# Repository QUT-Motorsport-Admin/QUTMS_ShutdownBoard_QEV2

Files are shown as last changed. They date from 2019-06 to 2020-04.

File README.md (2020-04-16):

QUTMS_Banner
# Shutdown Board V2
Saftey System shutdown board dedicated to managing the vehicle shutdown loop.

## Function
Disables the car by opening the shutdown loop if at least one shudown device reports a fault. It also reports which devices are open circuit in the shutdown loop using sense wires in the wiring harness.

## Subsystems
* Shutdown loop latching for HVD, IMD, BMS, PDOC, MCU and BSPD.
* Brake Sensor Plausibility Device (BSPD).
* Shutdown node sensing and reporting.

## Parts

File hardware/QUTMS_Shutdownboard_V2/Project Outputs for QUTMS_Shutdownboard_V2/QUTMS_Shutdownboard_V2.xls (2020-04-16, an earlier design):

Item # | Designator | Description | Name | Quantity | Manufacturer 1 | Manufacturer Part Number 1 | Footprint | LibRef | Note
1 | C1, C3, C4, C5, C15, C16 | CAP 100nF 16V ±5% 0603 (1608 Metric) Thickness 1mm SMD | CAP 100nF 16V 0603(1608) | 6 | KEMET | C0603C104J4RAC | CAPC0603(1608)100_M | CMP-1035-02583-1
2 | C2 | Chip Capacitor, 10 uF, +/- 10%, 16 V, -25 to 85 degC, 0805 (2012 Metric), RoHS, Tape and Reel | EMK212BJ106KG-T | 1 | Taiyo Yuden | EMK212BJ106KG-T | CAPC2013X135X50ML10T25 | CMP-2000-05449-1
3 | C6, C11 | CAP 100nF 16V ±10% 0603 (1608 Metric) Thickness 1mm SMD | CAP 100nF 16V 0603(1608) | 2 | Yageo | CC0603KRX7R7BB104 | CAPC0603(1608)100_N | CMP-1035-02584-1
4 | C12 | CAP 4.7nF 50V ±5% 0603 (1608 Metric) Thickness 1mm SMD | CAP 4.7nF 50V 0603(1608) | 1 | KEMET | C0603C472J5RACTU | CAPC0603(1608)100_M | CMP-1035-02202-1
5 | C13, C14 | CAP 22pF 16V ±5% 0603 (1608 Metric) Thickness 1mm SMD | CAP 22pF 16V 0603(1608) | 2 | KEMET | C0603C220J4GACTU | CAPC0603(1608)100_N | CMP-1035-00808-1
6 | C17, C18 | CAP 22pF 16V ±1% 0603 (1608 Metric) Thickness 1mm SMD | CAP 22pF 16V 0603(1608) | 2 | Vishay Vitramon | VJ0603A220FXJPW1BC | CAPC0603(1608)100_L | CMP-1035-00806-1
7 | C19 | CAP 100nF 25V ±5% 0603 (1608 Metric) Thickness 1mm SMD | CAP 100nF 25V 0603(1608) | 1 | Yageo | CC0603JRX7R8BB104 | CAPC0603(1608)100_N | CMP-1035-02587-1
8 | C20 | Chip Capacitor, 10 uF, +/- 10%, 25 V, -55 to 85 degC, 1210 (3225 Metric), RoHS, Tape and Reel | 12103D106KAT2A | 1 | Kyocera AVX | 12103D106KAT2A | CAPC3225X279X50LL20T25 | CMP-2000-05477-1
9 | C21 | CAP 10uF 16V ±10% 0805 (2012 Metric) Thickness 1mm SMD | CAP 10uF 16V 0805(2012) | 1 |  |  | CAPC0805(2012)100_L | CMP-1036-04928-1
10 | DS1 | Chip LED, Green, 574 nm, 40 pF, -55 to 85 degC, 2-Pin SMD, RoHS, Tape and Reel | LTST-C191KGKT | 1 | Vishay Lite-On | LTST-C191KGKT | LITE-ON-LTST-C191KRKT-2_V | CMP-2000-05198-1
11 | J1 | Conn Wire to Board RCP 34 POS 1.5mm Solder RA Thru-Hole Automotive Tube | 6437288-2 | 1 |  |  | TE_6437288-2 | 6437288-2
12 | K1, K2, K3, K4, K5, K6 | DPDT 2 Form C (CO) Low Power PCB Relay, 24 VDC, 8 A, -40 to 85 degC, 8-Pin THD, RoHS, Tube | RT424024 | 6 | TE Connectivity | RT424024 | TECO-RT424024_V | CMP-2000-06999-1
13 | L2 | Fixed Inductor, 10 uH, +/-20%, -55 to 125 degC, 2-Pin SMD (0805), RoHS, Tape and Reel | LQM21FN100M70L | 1 | Murata | LQM21FN100M70L | MURA-IND0805_L | CMP-2000-06587-1
14 | LED1, LED2, LED3, LED4 | LED, SMT, 0603(1608), 0.25mm Tthickness, Super Bright Orange | APG1608SEKC/T | 4 | Kingbright | APG1608SEKC/T | KING-LED0603-25-ORANGE_V | CMP-0239-00002-1
15 | P1, P2 | Header, 3-Pin, Right Angle | Header 3H | 2 |  |  | HDR1X3H | Header 3H
16 | P3 | UART Header | UART Header | 1 |  |  | HDR1X2 | Header 2
17 | P4 | Header, 3-Pin, Dual row | Header 3X2 | 1 |  |  | HDR2X3 | Header 3X2
18 | P5, P6, P7, P8, P9, P10 | Header, 2-Pin | Header 2 | 6 |  |  | HDR1X2 | Header 2
19 | Q1, Q3, Q5, Q7, Q9 | Power MOSFET, -20 V, -1 A, P-Channel, 3-Pin SOT-23, Pb-Free, Tape and Reel | NTR1P02T1G | 5 | ON Semiconductor | NTR1P02T1G | ONSC-SOT-23-3-318-08_V | CMP-1058-00751-1
20 | Q2, Q4, Q6, Q8, Q10, Q11, Q12 | Power MOSFET, 750 mA, 20 V, N-Channel, 3-Pin SOT-23, Pb-Free, Tape and Reel | MGSF1N02LT1G | 7 | ON Semiconductor | MGSF1N02LT1-G | ONSC-SOT-23-3-318-08_V | CMP-1058-00777-1
21 | R1, R3, R5, R29, R31, R33, R34, R36, R38, R39, R41, R43, R44, R45, R47, R49, R54 | 10K 0.1W 5% 0603 (1608 Metric) SMD | 10K 5% 0603(1608) | 17 | Yageo | RC0603JR-0710KL | RESC0603(1608)_N | CMP-1012-00098-1
22 | R2, R7, R9, R12, R15, R18, R27, R30, R35, R40, R46, R52 | 4K7 0.1W 5% 0603 (1608 Metric) SMD | 4K7 5% 0603(1608) | 12 | Vishay Dale | CRCW06034K70JNEB | RESC0603(1608)_N | CMP-1012-00090-1
23 | R4, R32, R37, R42, R48, R53 | 220R 0.1W 5% 0603 (1608 Metric) SMD | 220R 5% 0603(1608) | 6 | Bourns | CR0603-JW-221ELF | RESC0603(1608)_M | CMP-1012-00058-1
24 | R6, R8, R10, R11, R13, R14, R17, R19, R20, R21 | Resistor | Res1 | 10 |  |  | AXIAL-0.3 | Res1
25 | R16 | 51K 0.1W 5% 0603 (1608 Metric) SMD | 51K 5% 0603(1608) | 1 | Vishay Dale | CRCW060351K0JNEA | RESC0603(1608)_M | CMP-1012-00115-1
26 | R22 | 300R 0.1W 5% 0603 (1608 Metric) SMD | 300R 5% 0603(1608) | 1 | Vishay Dale | CRCW0603300RJNEA | RESC0603(1608)_N | CMP-1012-00061-1
27 | R23, R24 | 60R4 0.5W 1% 1210 (3225 Metric) SMD | 60R4 1% 1210(3225) | 2 | Yageo | RC1210FR-0760R4L | RESC1210(3225)_L | CMP-1015-00372-1
28 | R25, R26, R50, R55, R56 | 330R 0.1W 5% 0603 (1608 Metric) SMD | 330R 5% 0603(1608) | 5 | Bourns | CR0603-JW-331ELF | RESC0603(1608)_L | CMP-1012-00062-1
29 | R28 | 3K 0.1W 5% 0603 (1608 Metric) SMD | 3K 5% 0603(1608) | 1 | Vishay Dale | CRCW06033K00JNEA | RESC0603(1608)_M | CMP-1012-00085-1
30 | R51 | 1K 0.1W 5% 0603 (1608 Metric) SMD | 1K 5% 0603(1608) | 1 | Vishay Dale | CRCW06031K00JNEB | RESC0603(1608)_L | CMP-1012-00074-1
31 | SW1 | Tactile Switch, 50 mA, 12 VDC, -20 to 85 degC, 4-Pin SMD, RoHS, Bulk | 4-1437565-1 | 1 | TE Connectivity | 4-1437565-1 | TECO-4-1437565-1_V | CMP-2000-05602-1
32 | SW2 | Ultra-Small Tactile Switch, 0.05 A, 12 V, -25 to 70 degC, 2-Pin SMD, RoHS, Tape and Reel | B3U-1000P | 1 | Omron | B3U-1000P | OMRON-B3U-1000_V | CMP-2100-03586-1
33 | U1 | Quad Differential Comparator, 2 to 30 V, 0 to 70 degC, 14-pin SOIC (D14), Green (RoHS & no Sb/Br), Tube | LM339D | 1 | Texas Instruments | LM339D | D0014A_L | CMP-2000-06548-1
34 | U2, U8, U9 | Single 2-Input Positive-NOR Gate, DBV0005A, LARGE T&R | SN74AHC1G02DBVR | 3 | Texas Instruments | SN74AHC1G02DBVR | DBV0005A_L | CMP-0859-00024-3
35 | U3 |  | MCP2517FD | 1 |  |  | MCP2517FD SOIC | MCP2517FD
36 | U4 |  | MCP2561 | 1 |  |  | MCP2561 SOIC | MCP2561
37 | U5 | Analog Multiplexer / Demultiplexer, 3 to 18 V, -55 to 125 degC, 24-Pin SOIC, Pb-Free, Tape and Reel | MC14067BDWR2G | 1 | ON Semiconductor | MC14067BDWR2G | ONSC-SOIC-24-751E-04_V | CMP-1307-00132-1
38 | U6 | 8-bit AVR Microcontroller, 128KB Flash, 4KB EEPROM, 16KB SRAM, 44-pin TQFP, Industrial Grade (-40°C to 85°C) | ATmega1284P-AU | 1 | Microchip / Atmel | ATMEGA1284P-AU | 44A_N | CMP-0095-00577-1
39 | U7 | Fixed Low Drop Positive Voltage Regulator, 5V, 4-Pin SOT-223, Tape and Reel | LD1117S50CTR | 1 | STMicroelectronics | LD1117S50CTR | SOT-223_N | CMP-0244-00311-1
40 | U10, U11, U12, U13, U14, U15 | 1 Form A Solid State Relay, 2 A, -40 to 85 degC, 6-Pin SMD, RoHS, Tape and Reel | VO14642AABTR | 6 | Vishay | VO14642AABTR | VISH-VO14642AABTR_V | CMP-2000-07398-1
41 | X1 |  | Crystal 20MHz | 1 |  |  | Crystal 20MHz | Crystal 20MHz
42 | X2 | ATS-SM Series Quartz Crystal, 16 MHz, -20 to 70 degC, 11.1 x 4.83 x 4.3mm SMD, RoHS, Tape and Reel | ATS16ASM-1 | 1 | CTS | ATS16ASM-1 | CTS-ATS-SM-XTAL-2 | CMP-0585-00002-2

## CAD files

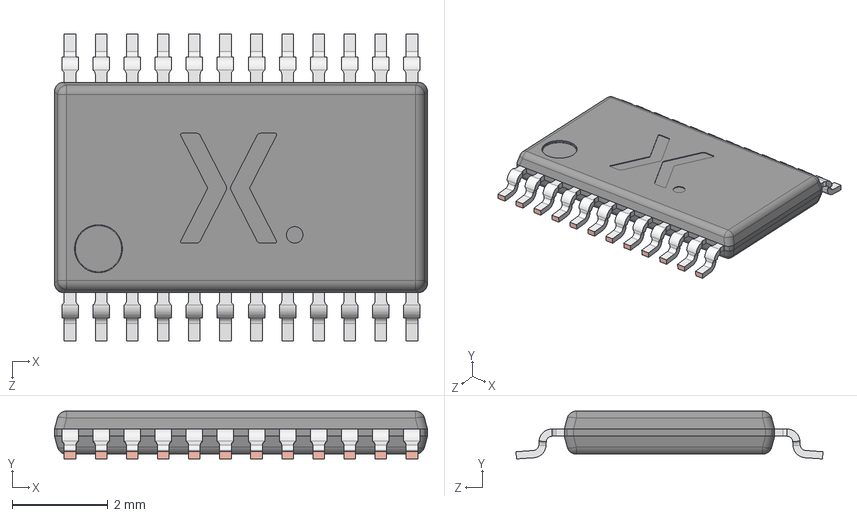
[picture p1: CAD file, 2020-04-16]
hardware/QUTMS_Shutdownboard_V2_1/SOT355-1.step
7.80 x 1.00 x 6.42 mm
SOT355-1 Lower Mold body
SOT355-1 Lead
SOT355-1 Upper Mold body

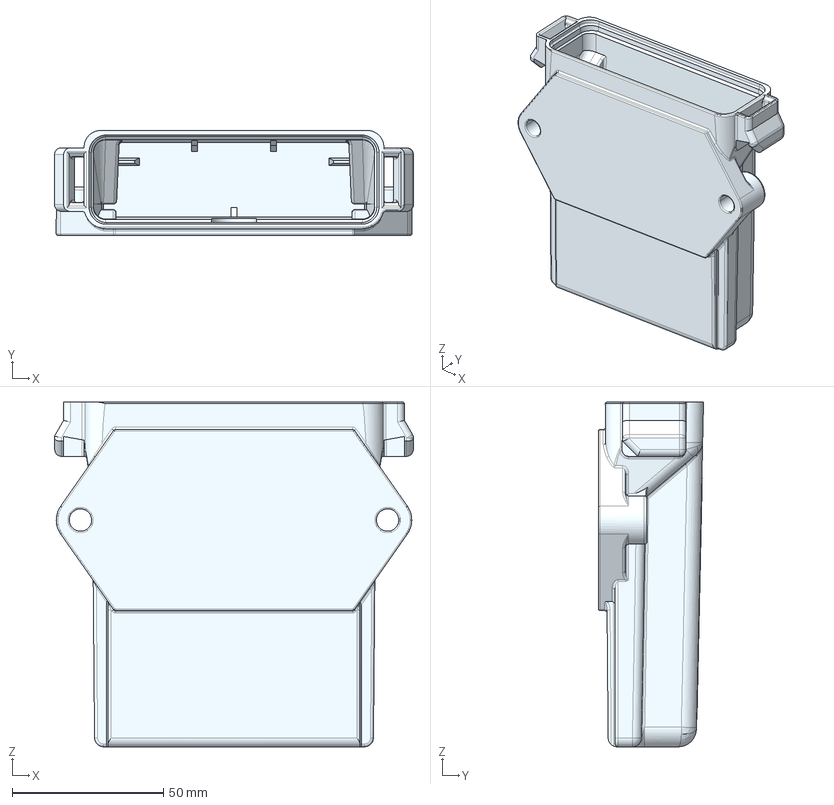
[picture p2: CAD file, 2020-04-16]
hardware/QUTMS_ShutdownBoard_V2_1_Assembly/c-eec-325x4b-e016-99-3d.stp
118.7 x 34.7 x 114.0 mm

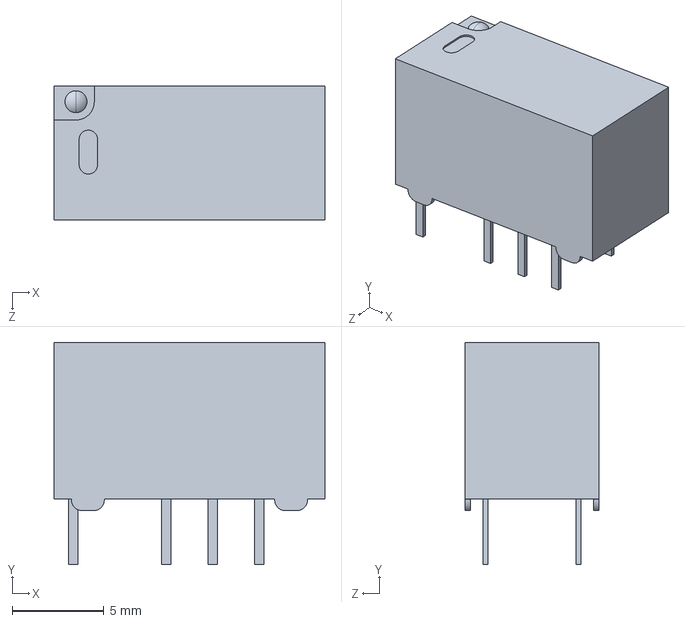
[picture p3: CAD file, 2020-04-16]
hardware/QUTMS_Shutdownboard_V2_1_BeforeSplit_FROZEN/G6S_2.step
14.8 x 12.2 x 7.30 mm

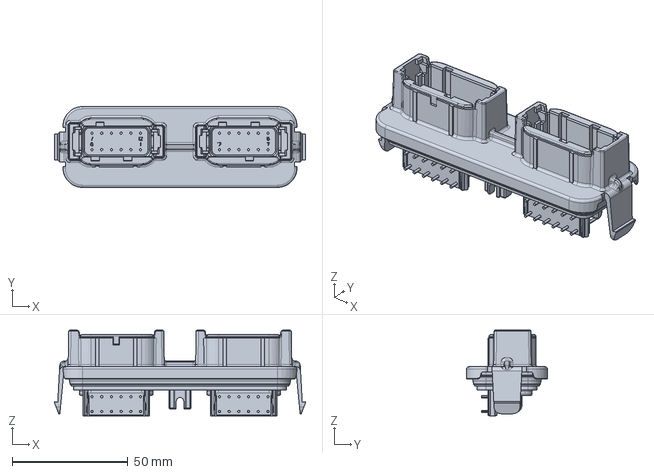
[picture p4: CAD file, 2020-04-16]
hardware/QUTMS_Shutdownboard_V2_1/c-dtm1312pa12pbgr01-c-3d.stp
108.3 x 35.0 x 36.9 mm

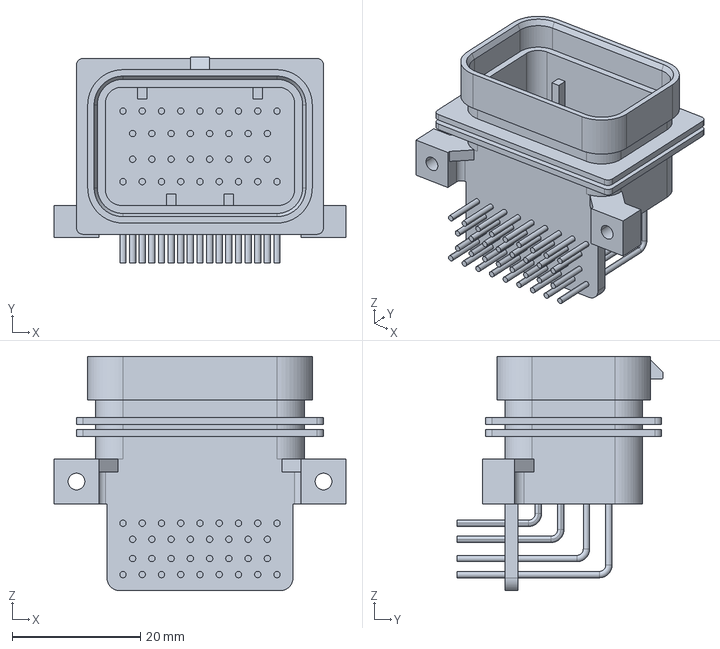
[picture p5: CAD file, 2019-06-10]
hardware/QUTMS_Shutdownboard_V2_1/c-6437288-2-c-3d.stp
45.5 x 32.1 x 36.5 mm

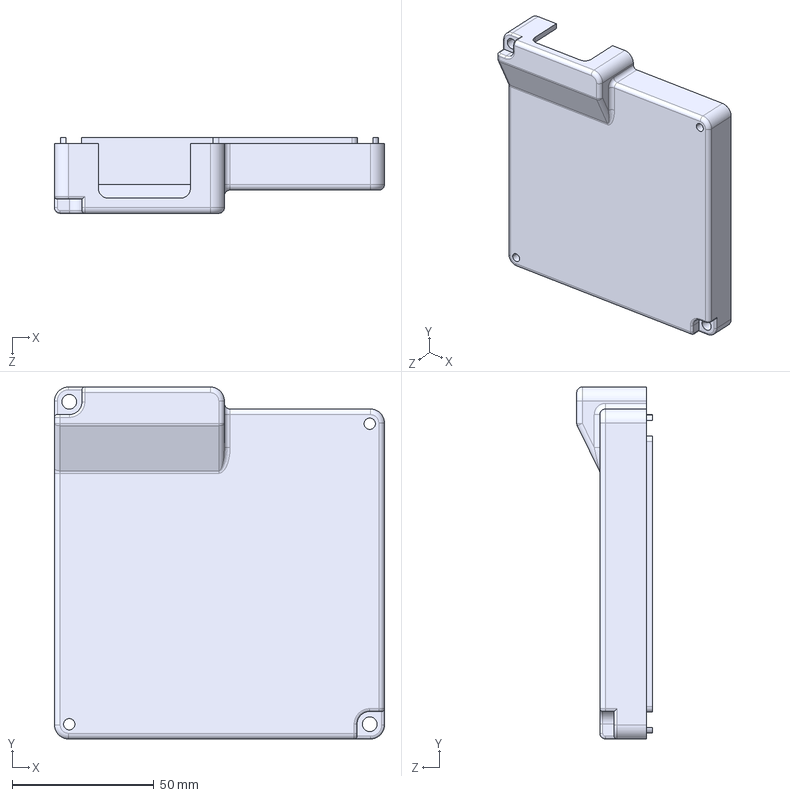
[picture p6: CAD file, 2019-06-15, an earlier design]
hardware/QUTMS_Shutdownboard_V2/SHUTDOWN BOARD CASE TOP.STEP
116.5 x 124.2 x 26.7 mm

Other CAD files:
hardware/QUTMS_Shutdownboard_V2/SHUTDOWN BOARD CASE BOTTOM.IGS
hardware/QUTMS_Shutdownboard_V2/SHUTDOWN BOARD CASE BOTTOM.STEP
hardware/QUTMS_Shutdownboard_V2/SHUTDOWN BOARD CASE TOP.IGS

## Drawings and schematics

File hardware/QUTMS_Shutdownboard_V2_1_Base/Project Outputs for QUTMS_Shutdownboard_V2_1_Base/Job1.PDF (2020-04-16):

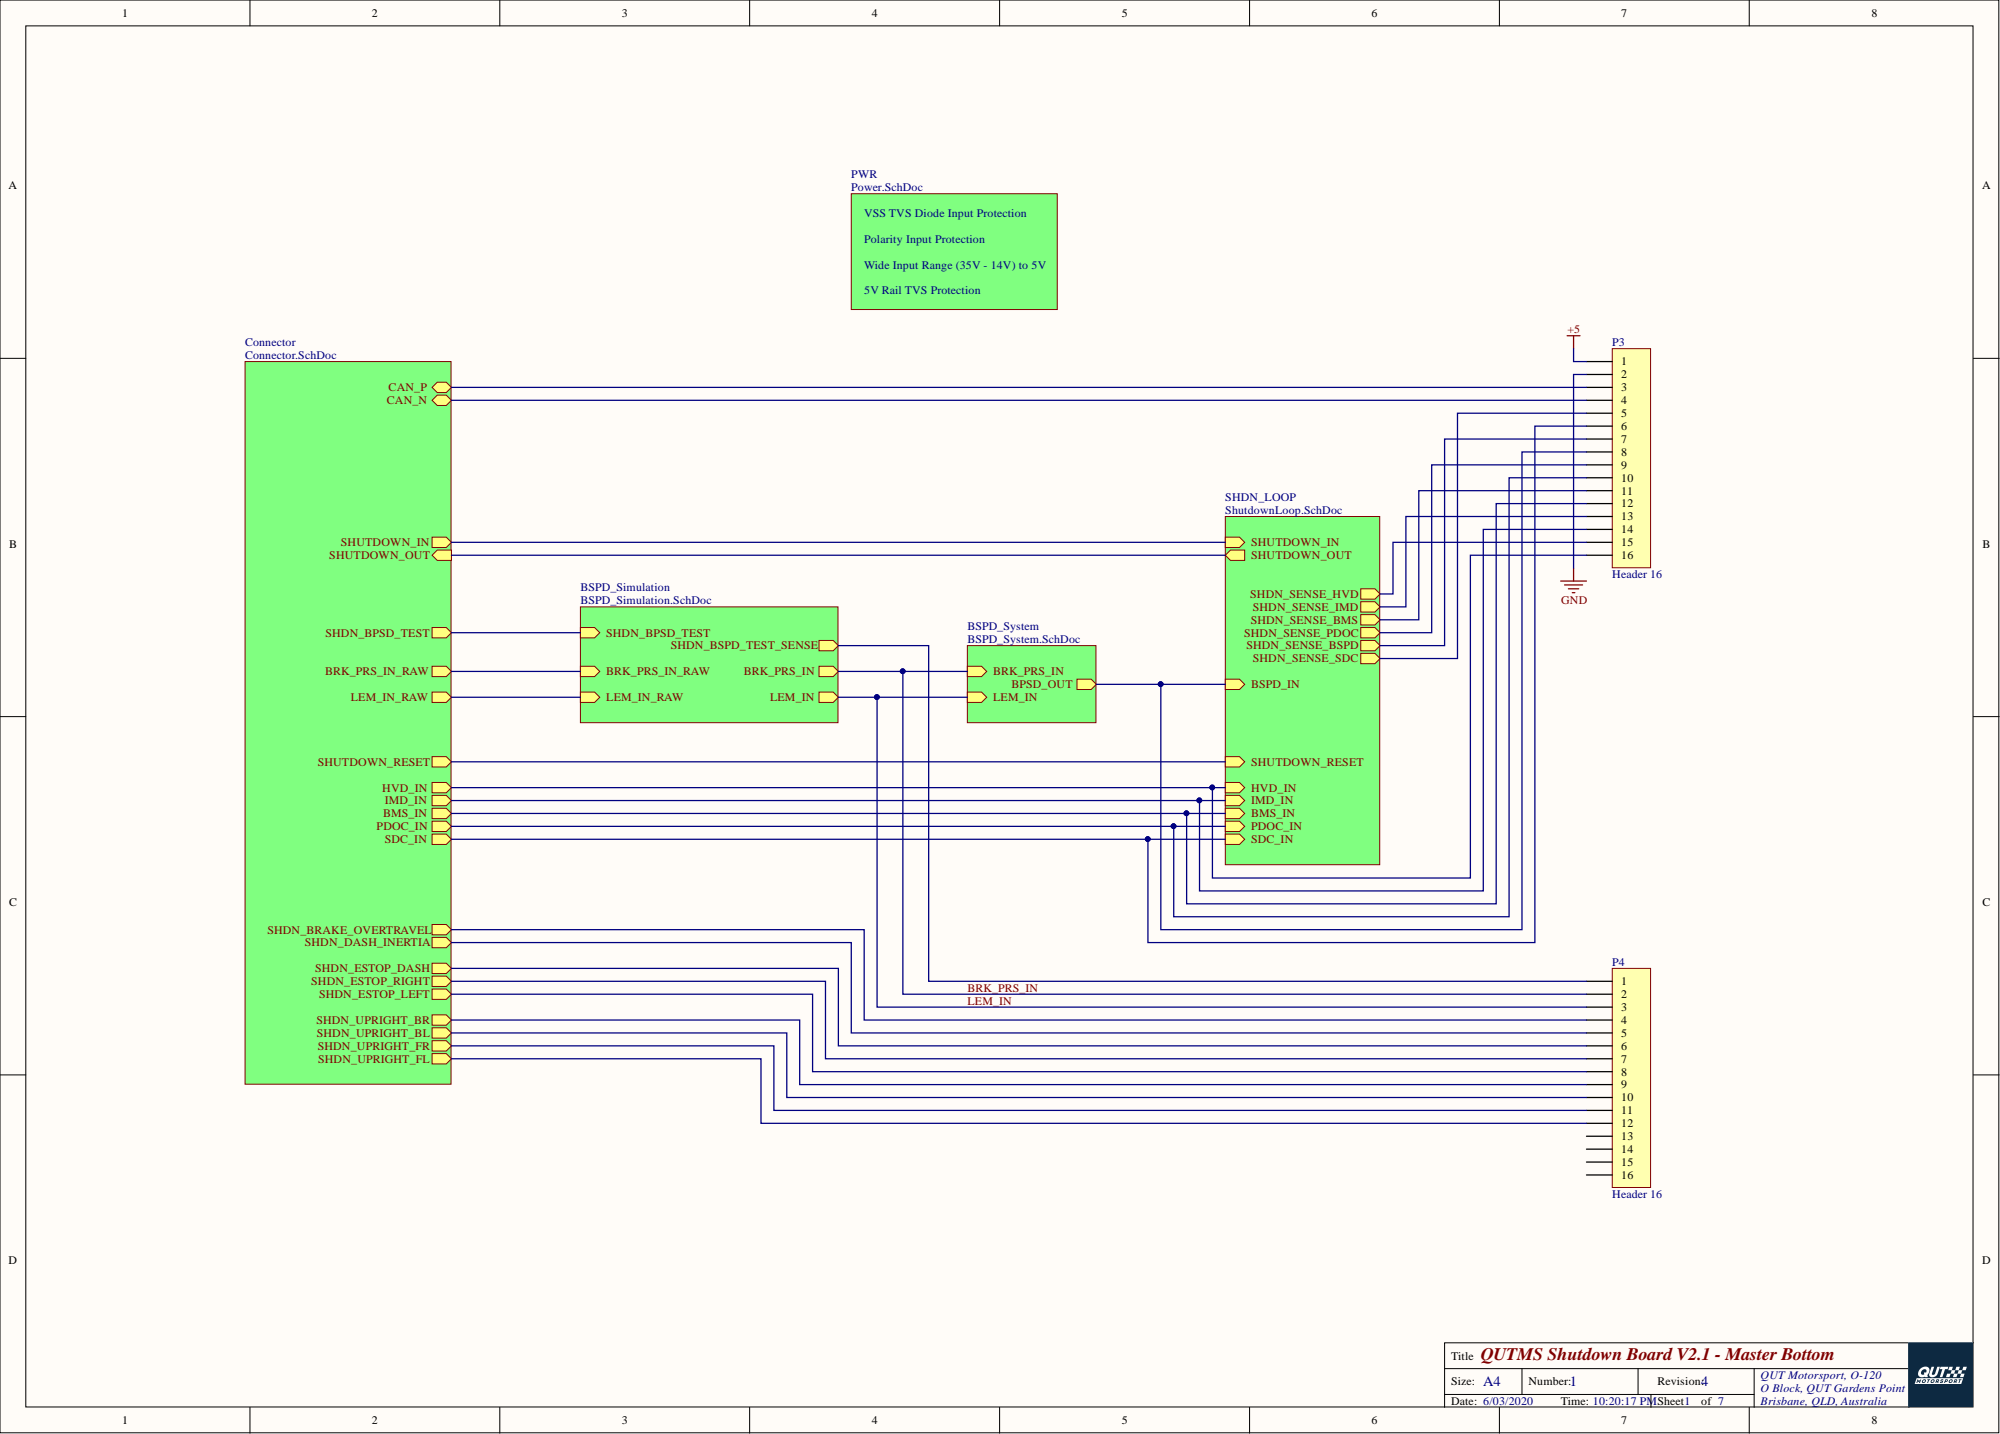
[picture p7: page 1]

SH D N _ L O O P
Sh u t d o w n L o o p.Sch D o c

BSPD _Simu lat i o n BSPD _Simu lat i o n.Sch D o c | | SH U T D O W N _ O U T SH D N _SE NSE _ H V D SH D N _SE NSE _IMD SH D N _SE NSE _BMS SH D N _SE NSE _PD O C SH D N _SE NSE _BSPD

BRK _PRS_IN | | SH D N _SE NSE _SD C

BPSD _ O U T L EM_IN | | BSPD _IN

SH U T D O W N _RESE T H V D _IN IMD _IN BMS_IN PD OC_IN SDC_IN

BRK _PRS_IN
L EM_IN

Q UTMS Shutdown Bo ard V2.1 - Master Botto m T i t l e

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

Date: / / T ime: : : 7 PM | Sheet o f

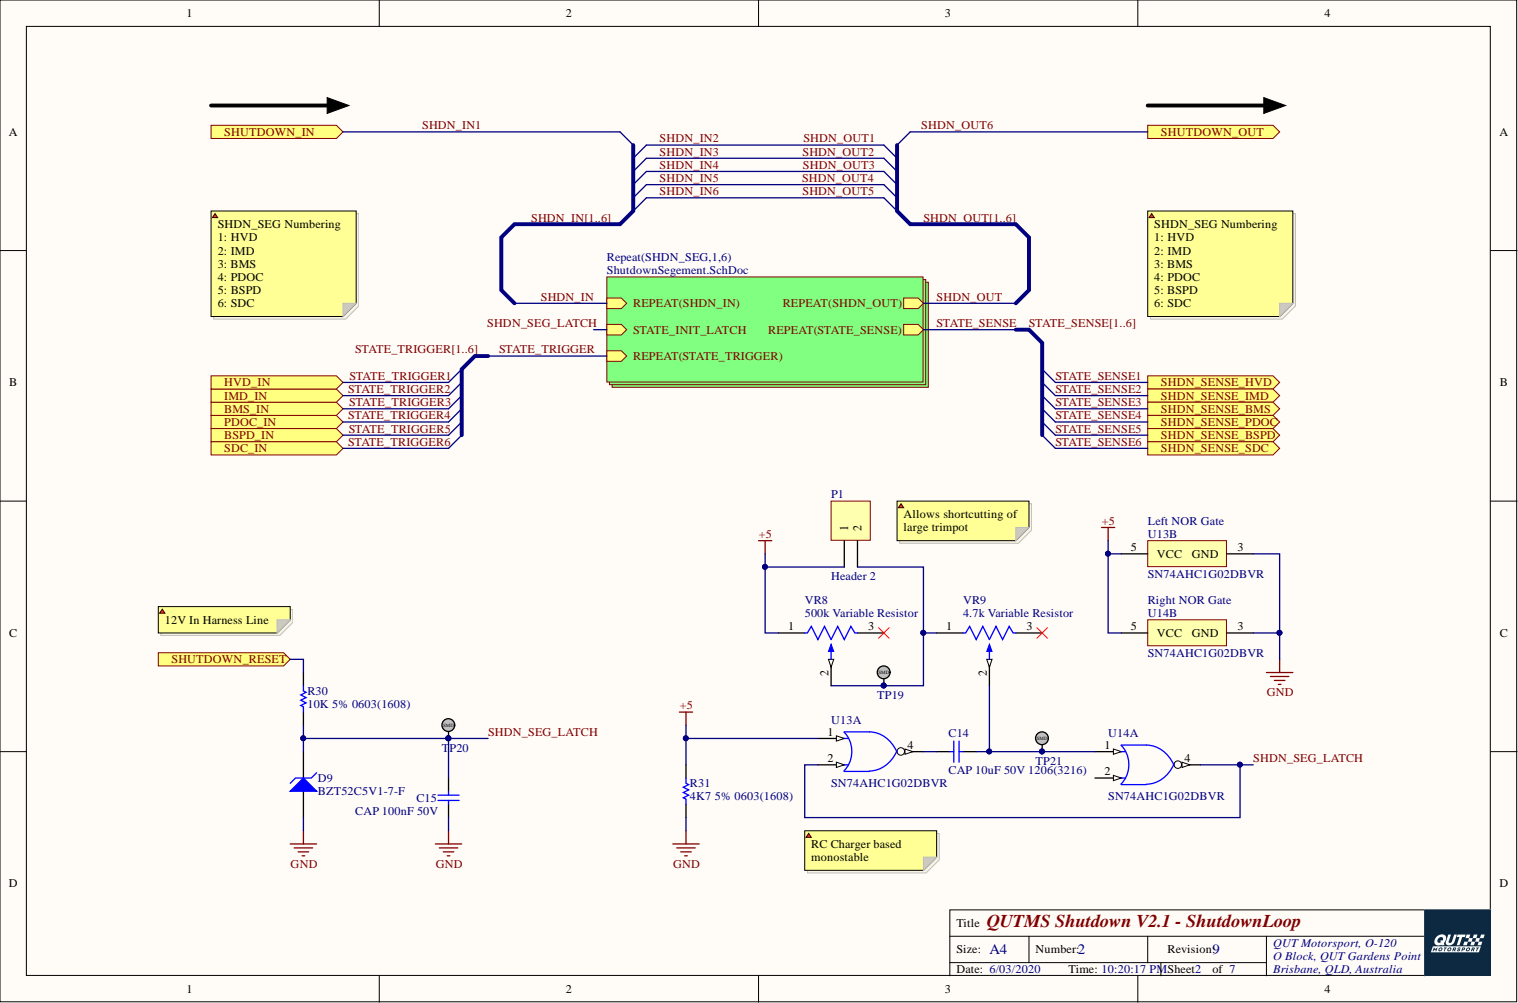
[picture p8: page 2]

QUTMS Shutdown V2.1 - ShutdownLoop Title

A4 Size: | Number: | Revision: | QUT Motorsport, O-120 O Block, QUT Gardens Point Brisbane, QLD, Australia

6/03/2020 Time: 10:20:17 PM | Sheet of

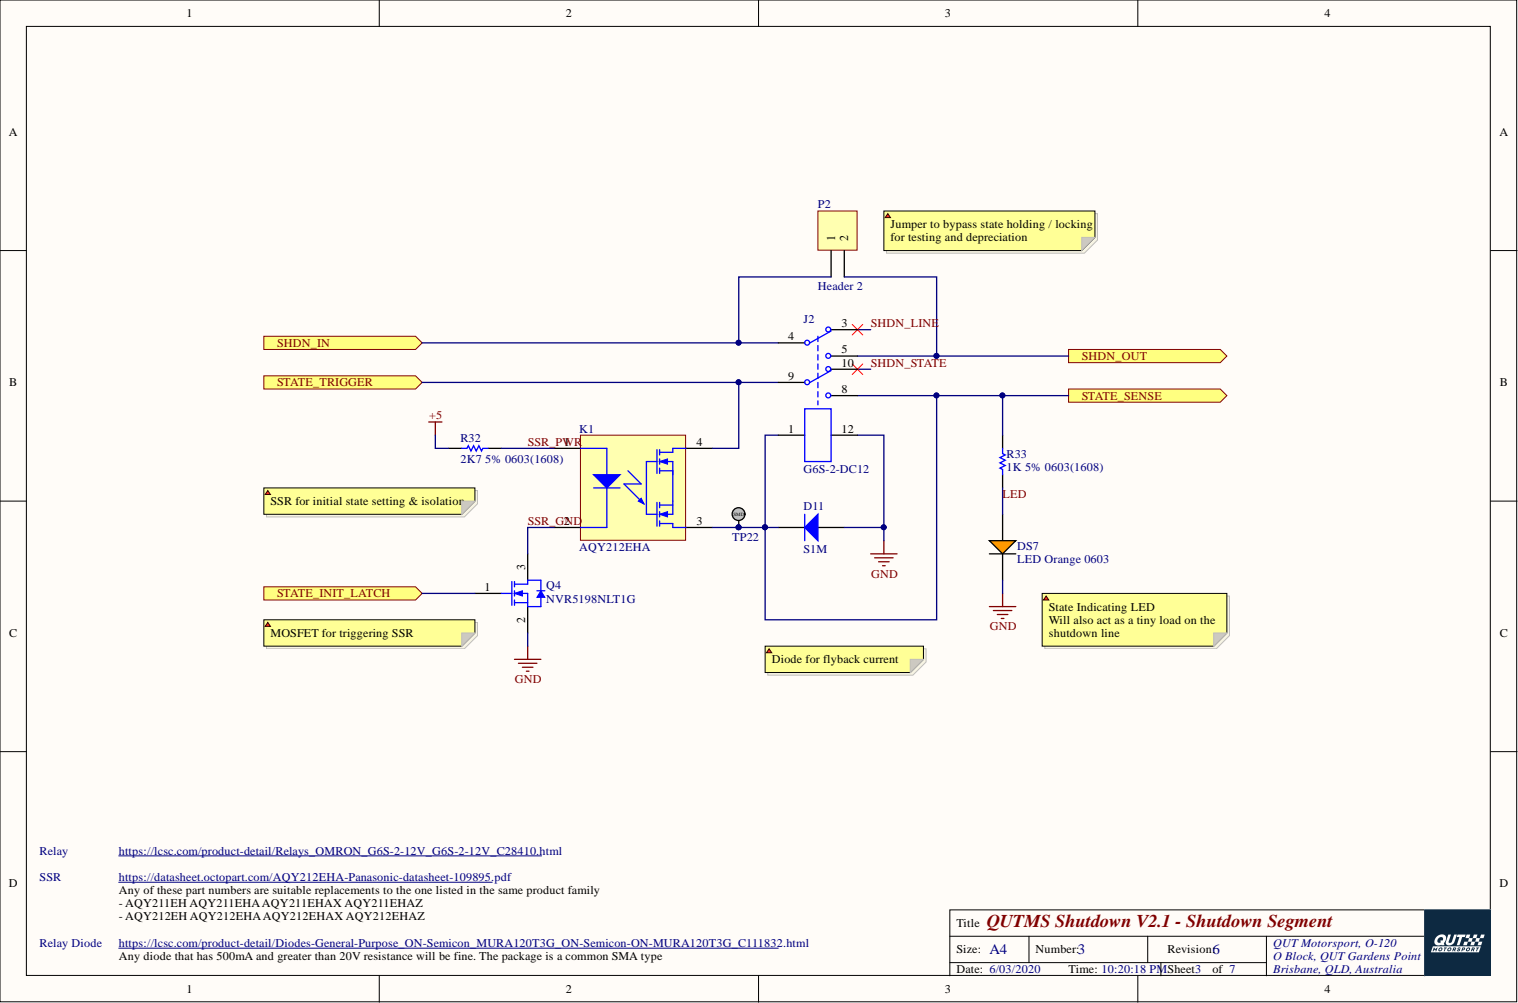
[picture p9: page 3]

Jumper to bypass state holding / locking
for testing and depreciation

SSR for initial state setting & isolation

State Indicating LED
Will also act as a tiny load on the
shutdown line

MOSFET for triggering SSR

Diode for flyback current

Any of these part numbers are suitable replacements to the one listed in the same product family
- AQY211EH AQY211EHAAQY211EHAX AQY211EHAZ
- AQY212EH AQY212EHAAQY212EHAX AQY212EHAZ

QUTMS Shutdown V2.1 - Shutdown Segment

Any diode that has 500mA and greater than 20V resistance will be fine. The package is a common SMA type

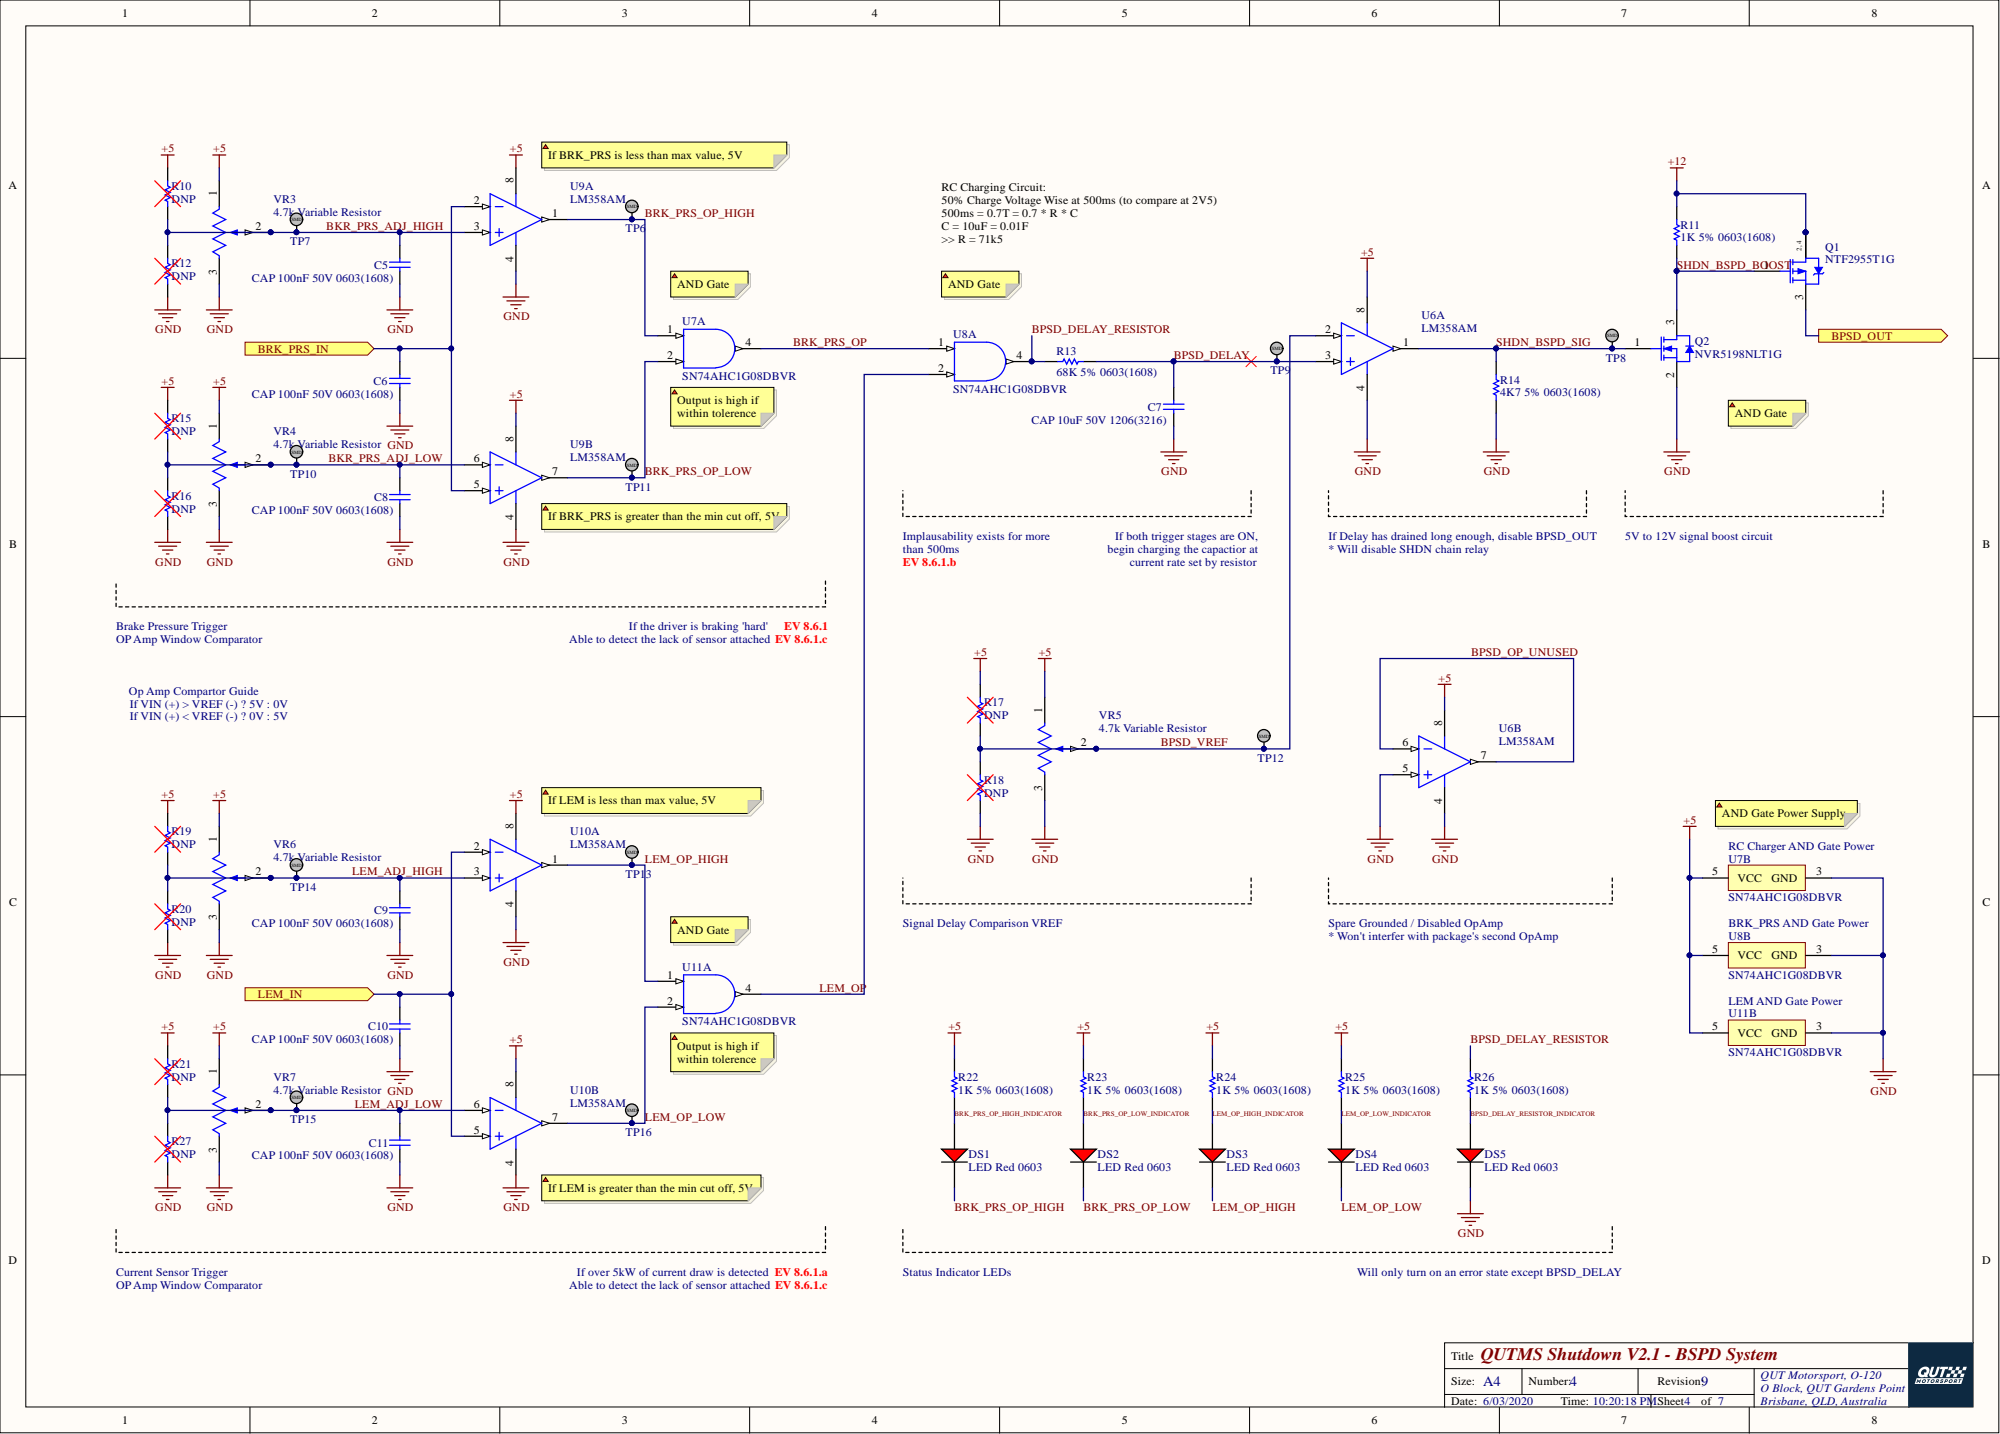
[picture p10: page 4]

If BRK_PRS is less than max value, 5V

RC Charging Circuit:
50% Charge Voltage Wise at 500ms (to compare at 2V5)

Output is high if
within tolerence

If BRK_PRS is greater than the min cut off, 5V

Implausability exists for more
than 500ms

If both trigger stages are ON,
begin charging the capactior at
current rate set by resistor

If Delay has drained long enough, disable BPSD_OUT
* Will disable SHDN chain relay

5V to 12V signal boost circuit

Brake Pressure Trigger
OP Amp Window Comparator

Able to detect the lack of sensor attached EV 8.6.1.c

Op Amp Compartor Guide
If VIN (+) > VREF (-) ? 5V : 0V
If VIN (+) < VREF (-) ? 0V : 5V

If LEM is less than max value, 5V

AND Gate Power Supply

RC Charger AND Gate Power

* Won't interfer with package's second OpAmp

LEM AND Gate Power

If LEM is greater than the min cut off, 5V

Current Sensor Trigger

If over 5kW of current draw is detected

Will only turn on an error state except BPSD_DELAY

QUTMS Shutdown V2.1 - BSPD System

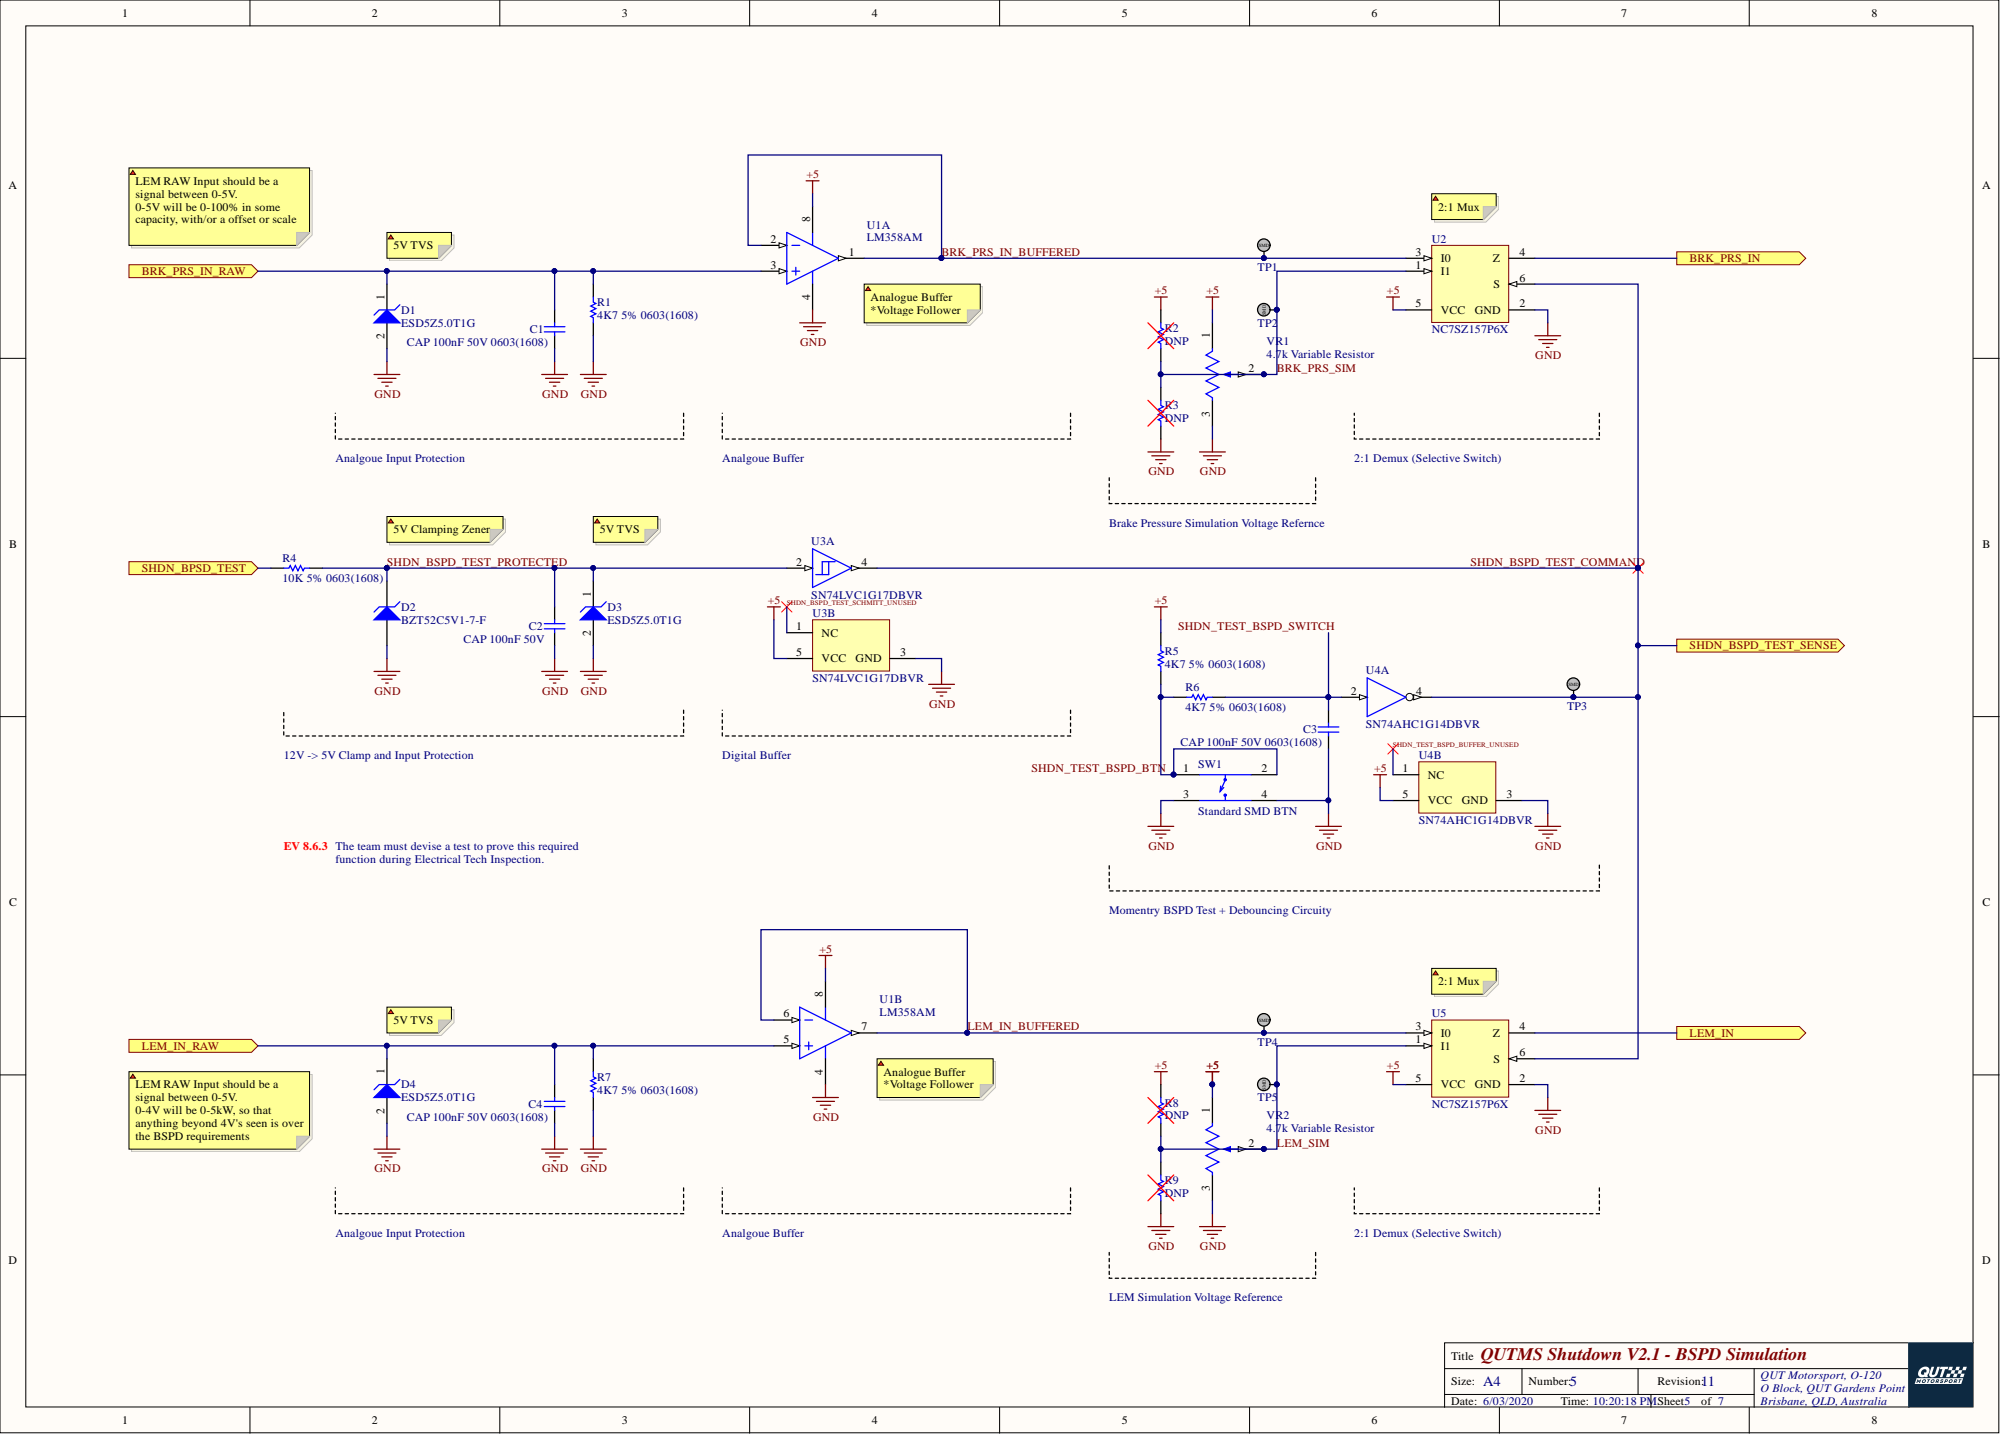
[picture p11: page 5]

LEM RAW Input should be a
signal between 0-5V.
0-5V will be 0-100% in some
capacity, with/or a offset or scale

Brake Pressure Simulation Voltage Refernce

12V -> 5V Clamp and Input Protection

EV 8.6.3 The team must devise a test to prove this required

function during Electrical Tech Inspection.

Momentry BSPD Test + Debouncing Circuity

0-4V will be 0-5kW, so that
anything beyond 4V's seen is over
the BSPD requirements

LEM Simulation Voltage Reference

QUTMS Shutdown V2.1 - BSPD Simulation

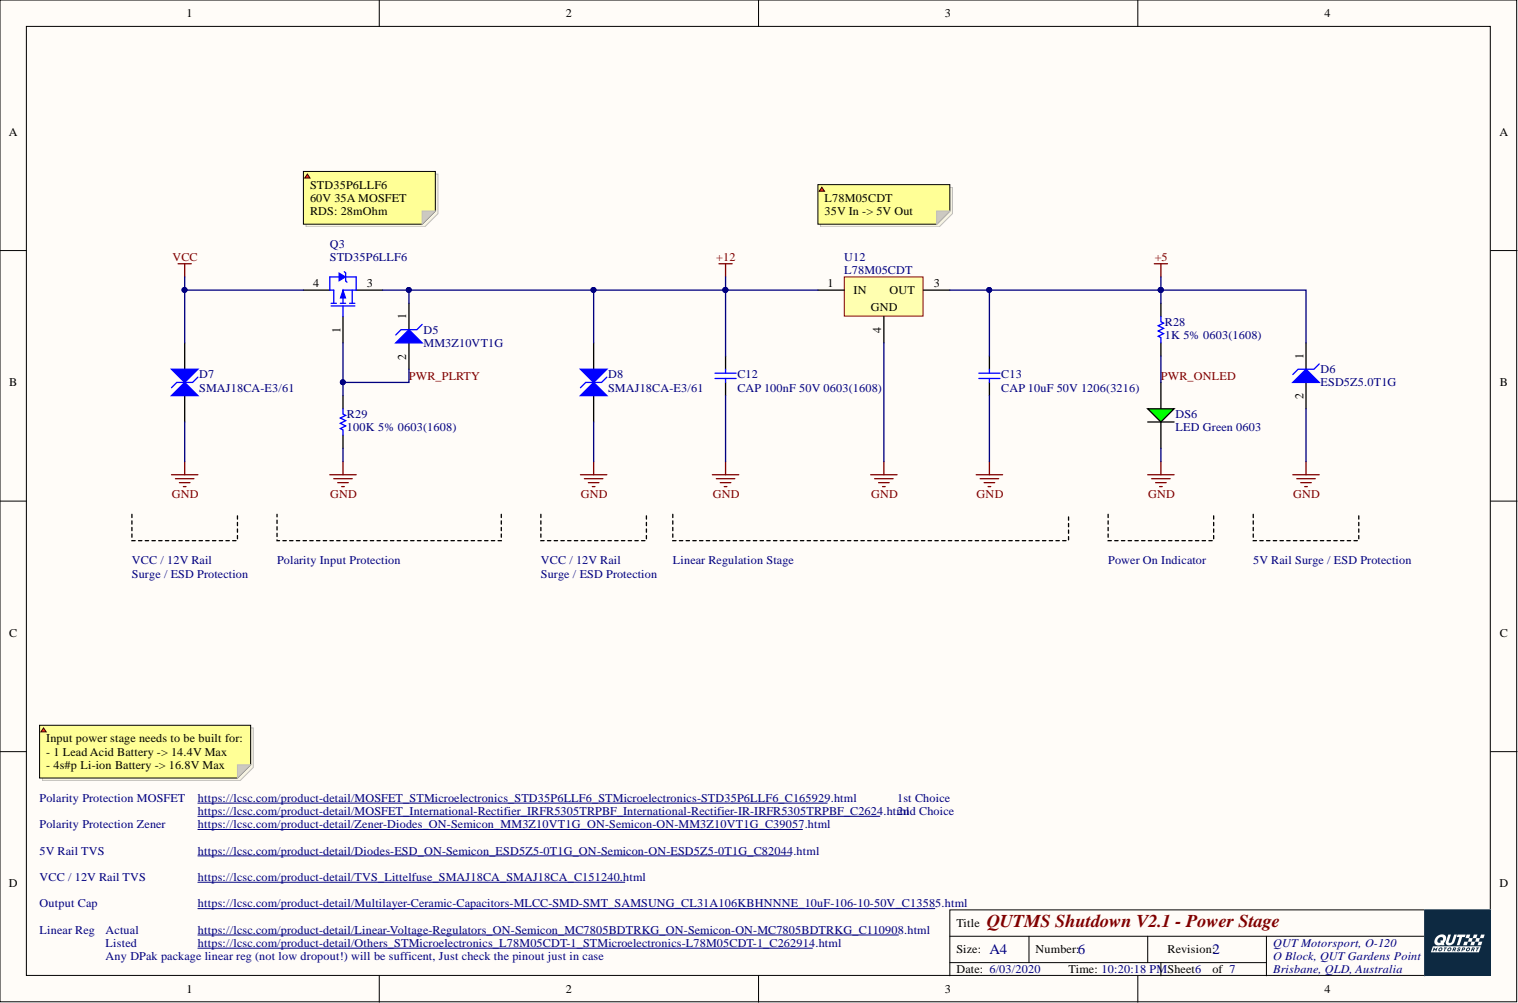
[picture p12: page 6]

ors-MLCC-SMD-SMT

Q UTMS Shutdown V2.1 - Power Stag e T i t l e

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

/ / T ime: : : 8 PM | Sheet o f

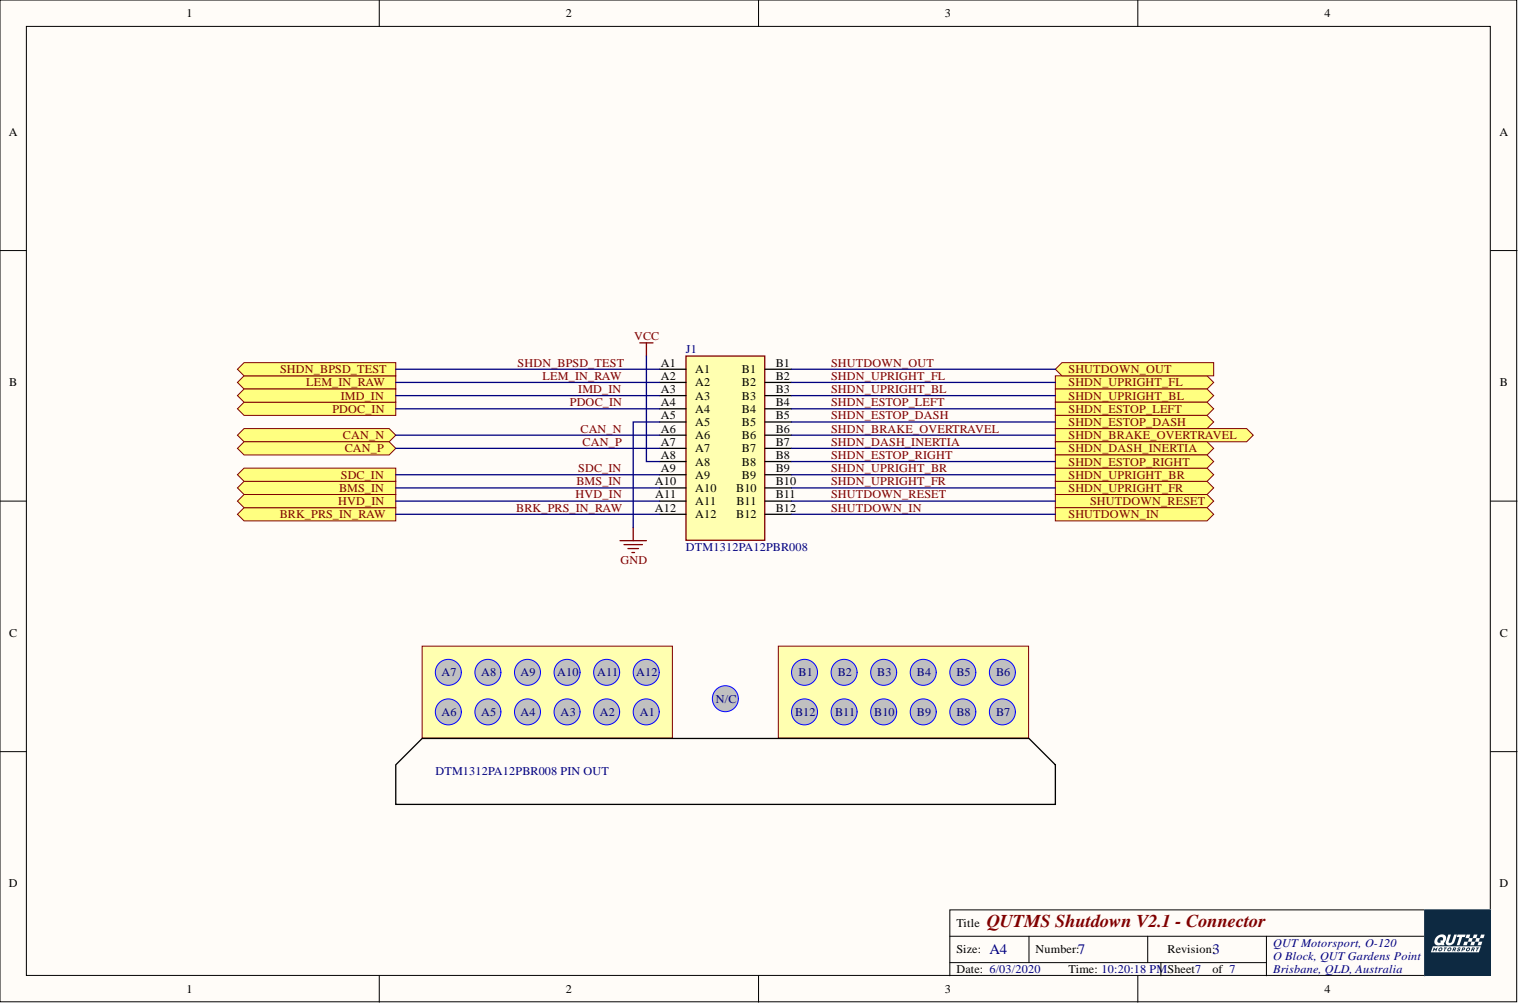
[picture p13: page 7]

Q UTMS Shutdown V2.1 - Connecto r T i t l e

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

/ / T ime: : : 8 PM | Sheet o f

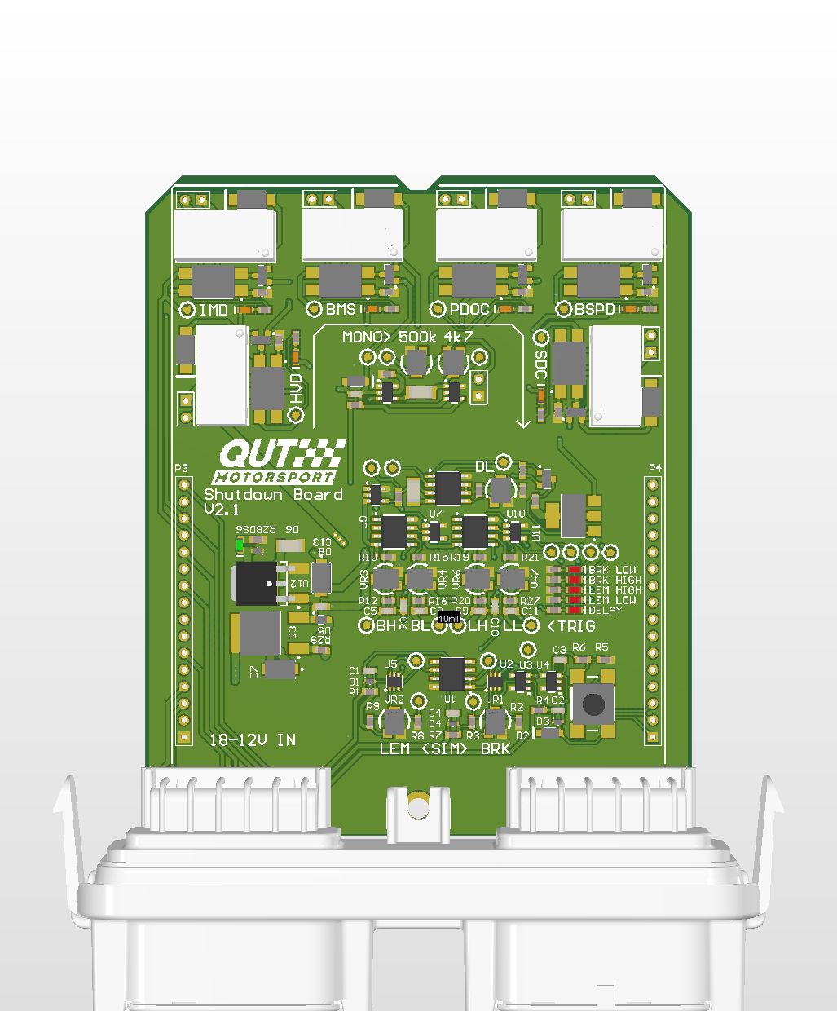
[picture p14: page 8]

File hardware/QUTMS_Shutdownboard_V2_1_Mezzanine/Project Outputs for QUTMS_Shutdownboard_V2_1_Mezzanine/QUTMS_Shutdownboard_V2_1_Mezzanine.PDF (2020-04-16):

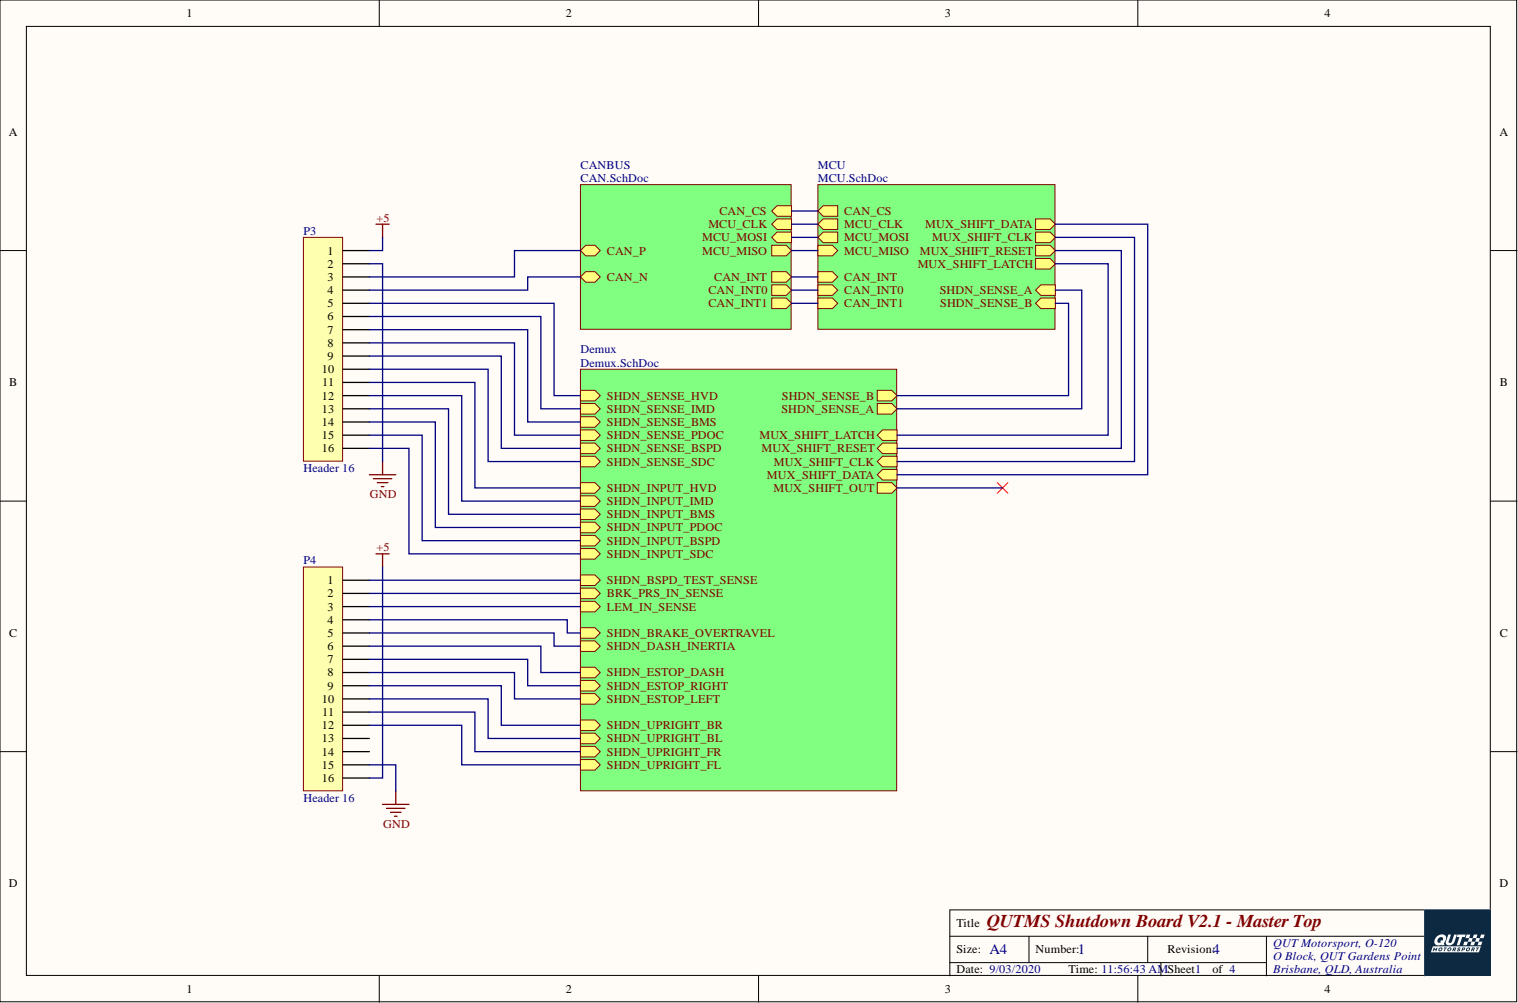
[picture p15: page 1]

QUTMS Shutdown Board V2.1 - Master Top Title

A4 Size: | Number: | Revision: | QUT Motorsport, O-120 O Block, QUT Gardens Point Brisbane, QLD, Australia

Date: 9/03/2020 Time: 11:56:43 AM | Sheet of

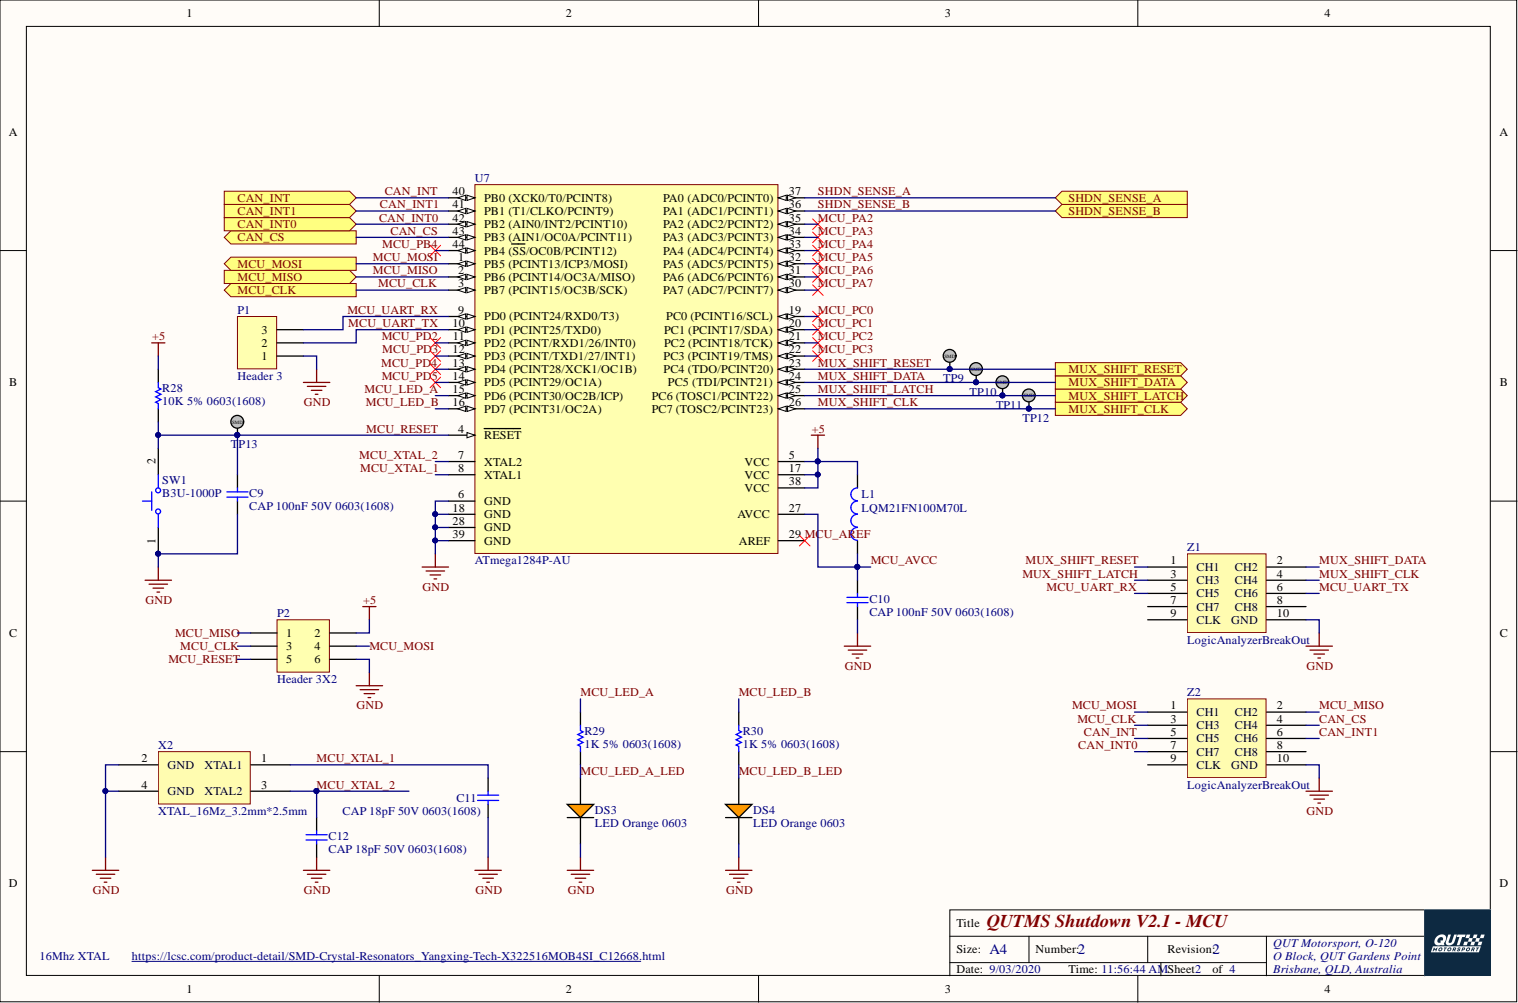
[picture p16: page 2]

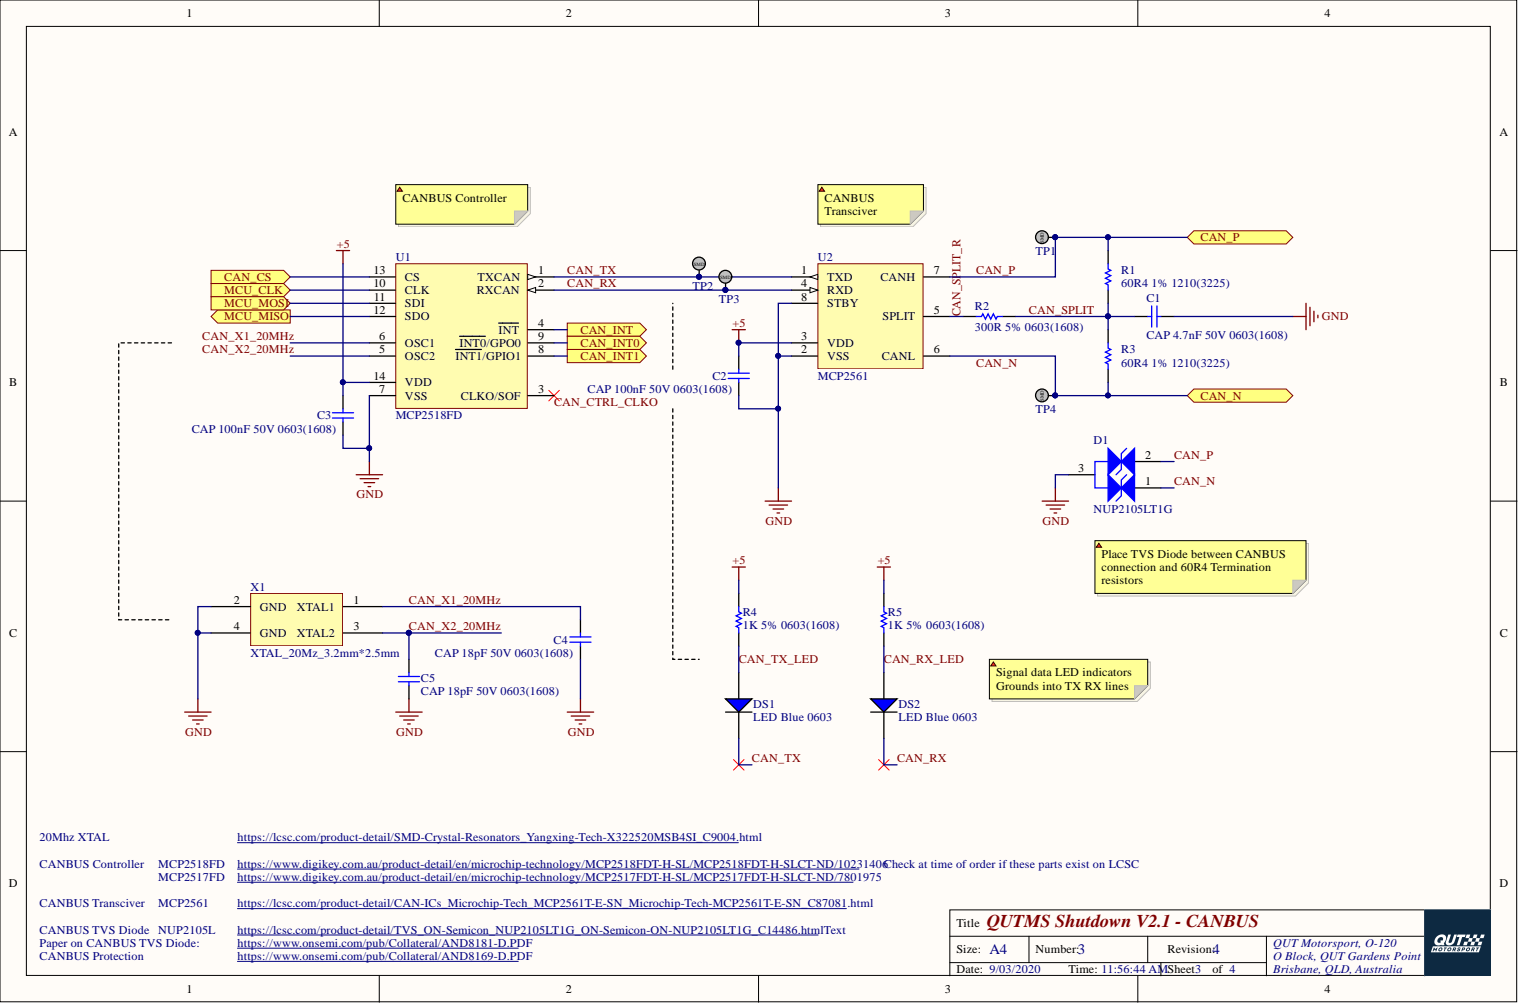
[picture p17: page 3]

Place TVS Diode between CANBUS
connection and 60R4 Termination
resistors

Signal data LED indicators
Grounds into TX RX lines

https://www.digikey.com.au/product-detail/en/microchip-technology/MCP2518FDT-H-SL/MCP2518FDT-H-SLCT-ND/10231406
https://www.digikey.com.au/product-detail/en/microchip-technology/MCP2517FDT-H-SL/MCP2517FDT-H-SLCT-ND/7801975

Check at time of order if these parts exist on LCSC

https://lcsc.com/product-detail/CAN-ICs_Microchip-Tech_MCP2561T-E-SN_Microchip-Tech-MCP2561T-E-SN_C87081.html

https://lcsc.com/product-detail/TVS_ON-Semicon_NUP2105LT1G_ON-Semicon-ON-NUP2105LT1G_C14486.htmlText

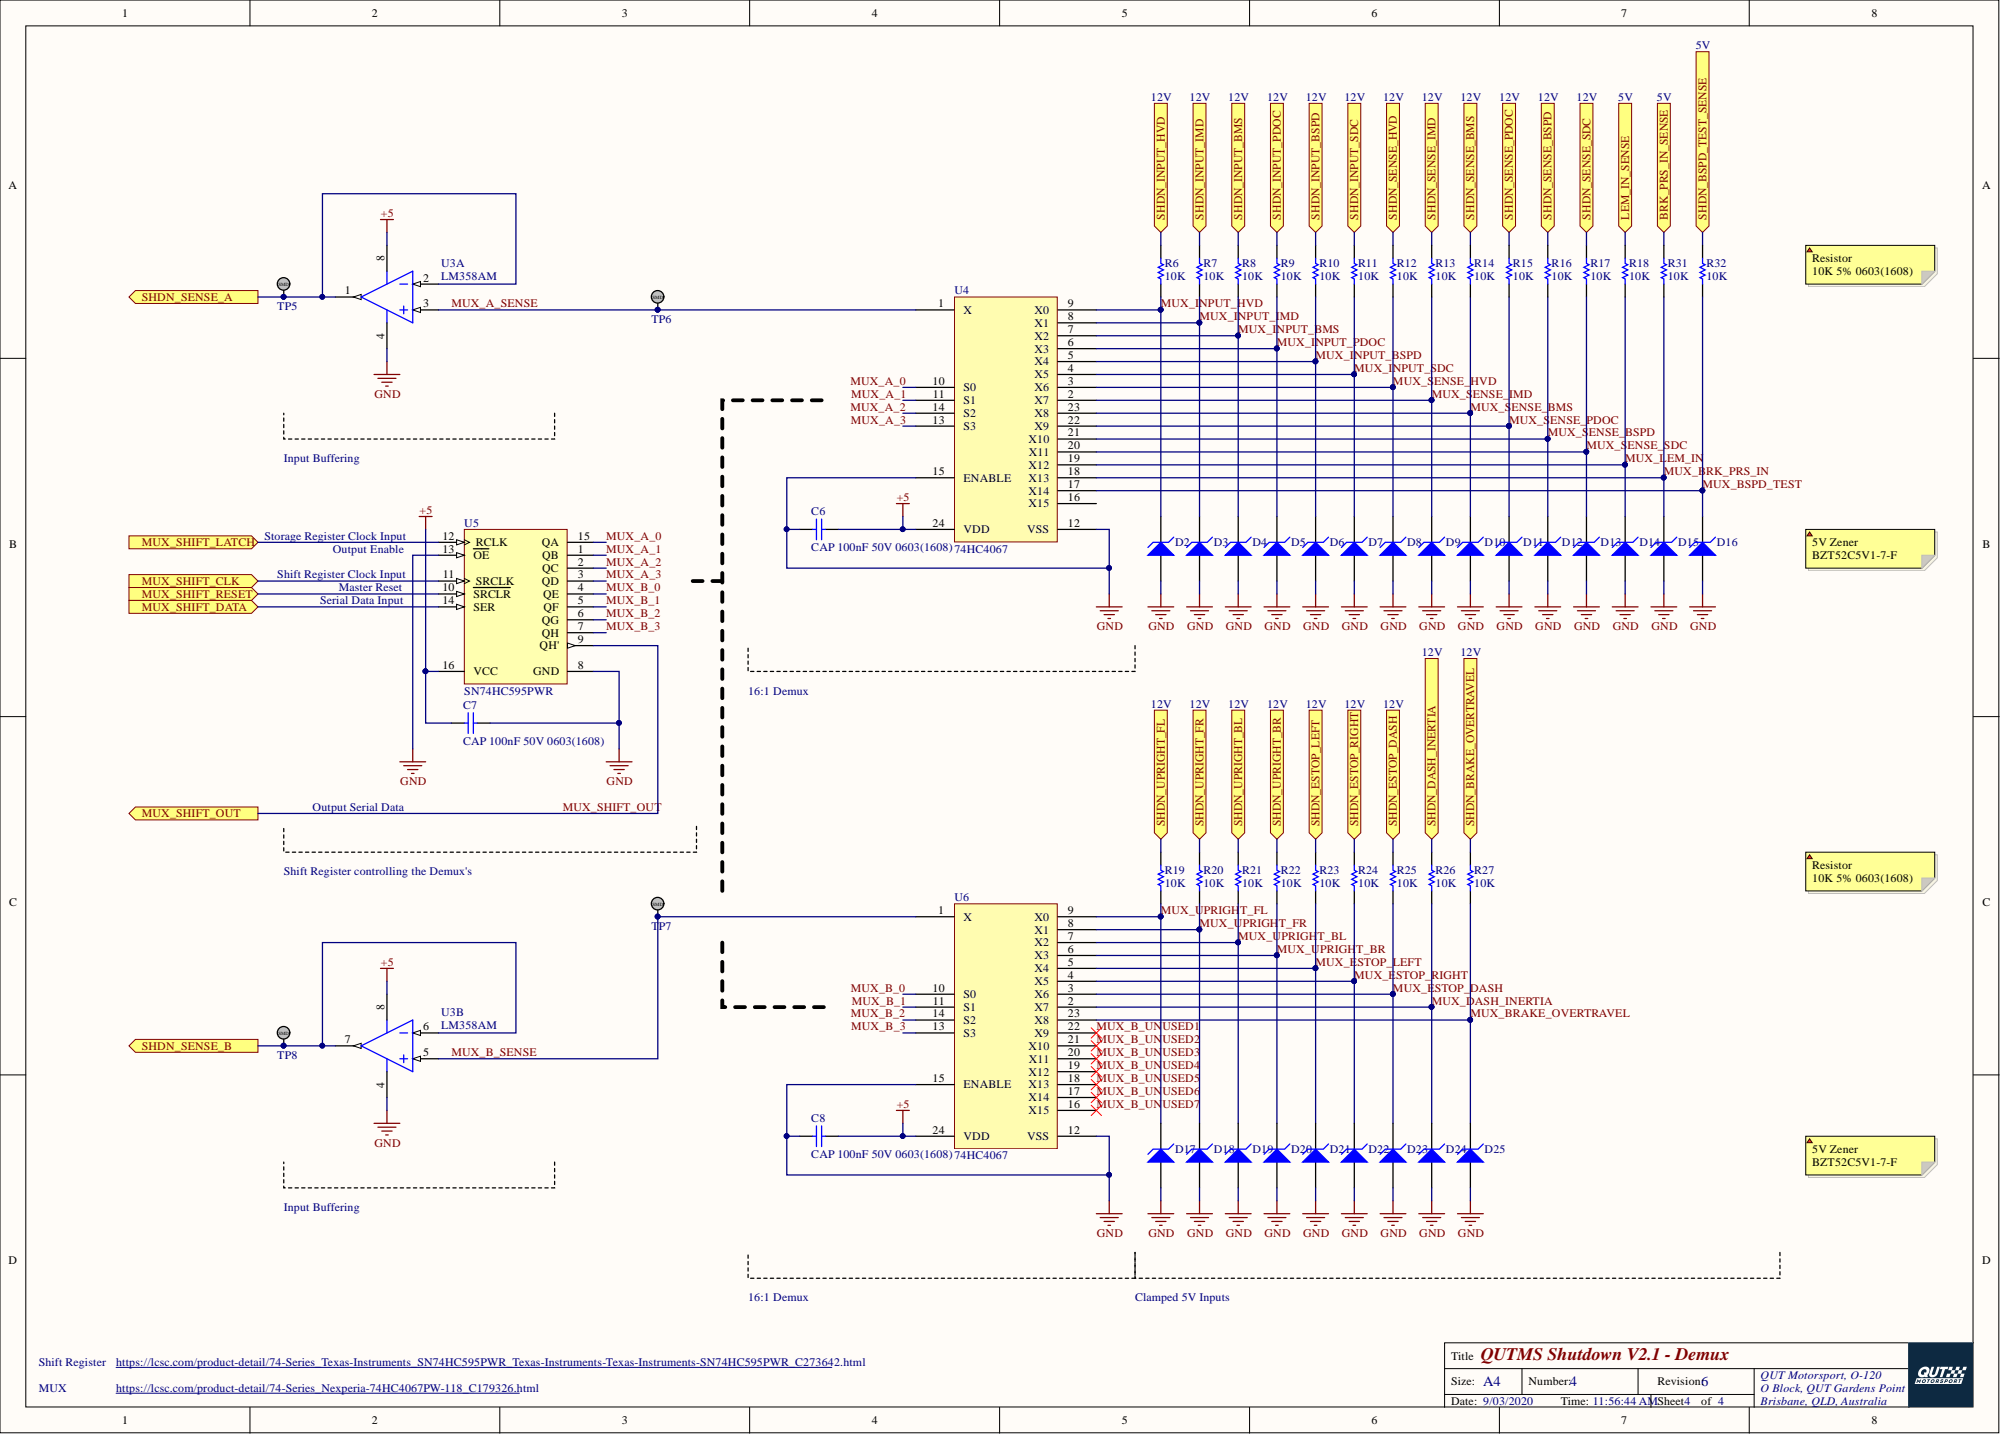
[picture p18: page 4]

Storage Register Clock Input

Shift Register Clock Input

SRCLR 10 SRCLK 11

SER 14

GND GND GND GND GND GND GND GND GND GND GND GND GND

Output Serial Data | | VCC 16

Shift Register controlling the Demux's

GND GND GND GND GND

Shift Register https://lcsc.com/product-detail/74-Series_Texas-Instruments_SN74HC595PWR_Texas-Instruments-Texas-Instruments-SN74HC595PWR_C273642.html


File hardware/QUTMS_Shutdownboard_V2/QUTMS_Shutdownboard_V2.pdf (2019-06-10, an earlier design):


Shutdown States
High Voltage Disconnect In
Insulation Monitoring Device
Battery Management System Alarm
Pre-Charge/Discharge Overload Circuit (PDOC)
Brake System Plausibilty Device (BPSD)

High Voltage Disconnect (HVD) Stage

Insulation Monitoring Device (IMD) Stage

Battery Management System (BMS) Alarm Stage

Pre-Charge/Discharge Overload Circuit (PDOC) Stage

QUTMS Shutdown V2 - Master Title | QUT Motorsport O-120 O Block QUT Gardnes Point Brisbane, 4000

Size: A3 | Number: 1 | Revision: *
Date: 11/06/2019 Time: 2:28:31 AM | | Sheet of 13

R:\Users\Jonn\Documents\git\qutms\QUTMS_ShutdownBoard_V2\hardware\QUTMS_Shutdownboard_V2\Master.SchDoc


https://datasheet.octopart.com/VO14642AABTR-Vishay-datasheet-68570096.pdf

http://www.ti.com/lit/ds/symlink/sn74ahc1g02.pdf

QUTMS Shutdown V2 - ShutdownLoop Title | QUT Motorsport O-120 O Block QUT Gardnes Point

Size: A3 | Number: 2 | Revision: *
11/06/2019 2:28:31 AM

R:\Users\Jonn\Documents\git\qutms\QUTMS_ShutdownBoard_V2\hardware\QUTMS_Shutdownboard_V2\ShutdownLoop.SchDoc


QUTMS Shutdown V2 - Connector Title | QUT Motorsport O-120 O Block QUT Gardens Point

A4 Size: | 3 Number: | * Revision:

R:\Users\Jonn\Documents\git\qutms\QUTMS_ShutdownBoard_V2\hardware\QUTMS_Shutdownboard_V2\Connector.SchDoc


Q T i t l e | Q UT Mo t o r sp o r t O-1 2 0 O B l ock Q UT G a rd nes P o i n t B r i s b a ne, 4

A4 Size: | N umber: | Rev i s i o n :

/ T ime: : A M | | Sheet f


Q UTMS Shutdown V2 - HVD _Filtering T i t l e | Q UT Mo t o r sp o r t O-1 2 0 O B l ock Q UT G a rden s P o i n t

A4 Size: | 5 N umber: | * Rev i s i o n :


Q UTMS Shutdown V2 - IMD _Filtering T i t l e | Q UT Mo t o r sp o r t O-1 2 0 O B l ock Q UT G a rden s P o i n t

A4 Size: | 6 N umber: | * Rev i s i o n :

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

A4 Size: | N umber: | Rev i s i o n :


Q UTMS Shutdown V2 - PD OC_Filtering T i t l e | Q UT Mo t o r sp o r t O-1 2 0 O B l ock Q UT G a rden s P o i n t

A4 Size: | 8 N umber: | * Rev i s i o n :


R13 Res1 1K

R20 Res1 1K

QUTMS Shutdown V2 - BSPD_System Title | QUT Motorsport O-120 O Block QUT Gardens Point

A4 Size: | 9 Number: | * Revision:

R:\Users\Jonn\Documents\git\qutms\QUTMS_ShutdownBoard_V2\hardware\QUTMS_Shutdownboard_V2\BSPD_System.SchDoc


LEM Test
Set to some voltage
Should simulate 5kW draw on
tractive system

QUTMS Shutdown V2 - BSPD_Simulation Title | QUT Motorsport O-120 O Block QUT Gardens Point

A4 Size: | 10 Number: | * Revision:

R:\Users\Jonn\Documents\git\qutms\QUTMS_ShutdownBoard_V2\hardware\QUTMS_Shutdownboard_V2\BSPD_Simulation.SchDoc


STBY 8

VSS 2 VDD 3

QUTMS Shutdown V2 - CANBUS Title | QUT Motorsport O-120 O Block QUT Gardens Point

A4 Size: | 11 Number: | * Revision:

R:\Users\Jonn\Documents\git\qutms\QUTMS_ShutdownBoard_V2\hardware\QUTMS_Shutdownboard_V2\CAN.SchDoc


GND 18

GND 39

QUTMS Shutdown V2 - MCU Title | QUT Motorsport O-120 O Block QUT Gardens Point

A4 Size: | 12 Number: | * Revision:

R:\Users\Jonn\Documents\git\qutms\QUTMS_ShutdownBoard_V2\hardware\QUTMS_Shutdownboard_V2\MCU.SchDoc

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

A4 Size: | N umber: | Rev i s i o n :

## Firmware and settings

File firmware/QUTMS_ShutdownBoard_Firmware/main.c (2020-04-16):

/*
 * QUTMS_ShutdownBoard_Firmware.c
 *
 * Created: 18/09/2019 12:51:26 PM
 * Author : Zoe Goodward
 */

#define F_CPU 16000000UL /* CPU clock in Hertz */

#include <avr/io.h>
#include <util/delay.h>
#include <avr/interrupt.h>
#include <avr/pgmspace.h>

#include "input.h"
#include "UART.h"
#include "spi.h"
#include "adc.h"
#include "MCP2517.h"
#include "MCP2517_reg.h"

uint8_t SHUTDOWN_BOARD_DATA[5] = {0};

/*============================================================================
Function:   shutdown_board_init()
------------------------------------------------------------------------------
Purpose :   consolidates all the functions required for the initialisation of
			the Shutdown board
Input   :   none
Returns :   void
Notes   :
============================================================================*/
void shutdown_board_init() 
{
	DDRD = 0b11000010; // LEDs as outputs
	DDRB = 0b10111000; // MOSI and SCK and CAN_CS as output, SS output

	CAN_CS_PORT |= (1 << CAN_CS); // CS high to turn off
	
	adc_init();
	uart0_init(9600);
	spi_init(0,0); // 1,0
	MCP2517_init();
	sei(); // Enable interrupts
}

int main(void)
{
    shutdown_board_init();
	
	uint8_t data[8] = {0};
	CAN_RECEIVE_ADDRESS receiveID;
	uint8_t numDataBytes;
	
    while(1) 
    {
		MCP2517_recieveMessage(&receiveID, &numDataBytes, data);
		if(receiveID == CAN_RECEIVE_ID_SHUTDOWN >> 18) {	
			MCP2517_transmitMessage(CAN_SEND_ID_SHUTDOWN, 5, SHUTDOWN_BOARD_DATA); // Respond to CC Heartbeat
		}
			
		_delay_ms(100);
    }
}

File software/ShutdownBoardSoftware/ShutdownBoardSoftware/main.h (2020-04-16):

/*
 * main.h
 *
 * Created: 7/09/2019 8:40:00 PM
 * Author : Jonn
 */ 

// Define LEDs
// LED A => PIN 15, PD6
// LED B => PIN 16, PD7
#define LED_A_ON		PORTD |= 0b01000000
#define LED_A_OFF		PORTD &= ~0b01000000
#define LED_A_TOGGLE	PORTD ^= ~0b01000000

#define LED_B_ON		PORTD |= 0b10000000
#define LED_B_OFF		PORTD &= ~0b10000000
#define LED_B_TOGGLE	PORTD ^= ~0b10000000

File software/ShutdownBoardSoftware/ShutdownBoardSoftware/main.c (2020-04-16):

/*
 * ShutdownBoardSoftware.c
 *
 * Created: 7/09/2019 9:41:05 PM
 * Author : Jonn
 */ 

#define F_CPU 16000000

#include <avr/io.h>
#include <util/delay.h>
#include "main.h"

uint8_t init(void) {
	// Set Up Ports
	//		 LED B			  LED A
	DDRD = (1 << PORTD7) || (1 << PORTD6);
	PORTD = (1 << PORTD7) || (1 << PORTD6);
	return 0;
}

uint8_t mux_setCh(uint8_t channel) {
	// MUX Channels
	// Ch A => Pin 35, PA2
	// Ch B => Pin 34, PA3
	// Ch C => Pin 33, PA4
	// Ch D => Pin 32, PA5
	
	// Input checking
	if (channel >= 15) channel = 15;
	
	PORTA = channel << 2; // Since the only other channel is SHDN_SENSE on PA0, we can always set to 0 and not have a problem
	_delay_us(1); // Waiting 1us (1/100th of a ms), to let the MUX switch over. MUX datasheet max switch time is 700ns = 1us * 0.7
	return channel;
}

int main(void) {
	while (1) {
		LED_A_ON;
		LED_B_OFF;
		_delay_ms(500);
		LED_A_OFF;
		LED_B_ON;
		_delay_ms(500);
	}
}

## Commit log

2019-03-25 add some project files, will clean up later
    [BSPD.SchDoc, CAN.SchDoc, QUTMS_ShutdownBoard_V2.PrjPcb]
2019-04-15 HV board
    [CAN.SchDoc, PCB1.PcbDoc, QUTMS_HVBoard.PrjPcb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]
2019-04-23 Moved HV Board work to QUT-Motorsport/HVBoard repo, removed ShutdownV2 work as it was effectivly nothing
    [BSPD.SchDoc, CAN.SchDoc, PCB1.PcbDoc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]
2019-04-23 Outline for board started
    [Master.SchDoc, QUTMS_Shutdownboard_V2.PrjPcb, ShutdownSafety.SchDoc]
2019-06-10 Schematic ready for reviewal
    [6437288-2.PcbLib, 6437288-2.SchLib, BMS_FIltering.SchDoc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]
2019-06-12 Part of the way though routing out the shutdown board
    [CAN.SchDoc, Connector.SchDoc, QUTMS_Shutdownboard_V2.PrjPcb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]
2019-06-12 Finished shutdown board
    [CAN.SchDoc, Connector.SchDoc, Demux.SchDoc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]
2019-06-14 Board finished, exported gerbers. Freeze Rev1
    [CAN.SchDoc, MCU.SchDoc, QUTMS_Shutdownboard_V2.PrjPcb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]
2019-06-15 Added cases
    [SHUTDOWN BOARD CASE BOTTOM.IGS, SHUTDOWN BOARD CASE BOTTOM.STEP, SHUTDOWN BOARD CASE TOP.IGS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]
2019-11-29 Add basic libraries and test and confirm MCP2517 library is working and board can send and receive messages.
2020-04-16 Added the shutdown board V1.1 intermin files. A bit up in the air currently
    [12To5VoltIsolated.SchDoc, 12VInputProtection.SchDoc, 6437288-2.PcbLib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]
